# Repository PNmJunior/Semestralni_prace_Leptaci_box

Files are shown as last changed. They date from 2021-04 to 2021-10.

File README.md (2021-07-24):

# Semestrální práce Leptací box
Jedná se o semestrální prácí Pavla Ňachaje z předmětu PPC.
## Cíl
Sestrojit zařízení, které usnadní a zefektivní leptání oboustraných spojů.
## Výsledek
Podařilo se mi vytvořit zařízení a k tomu řídicí aplikaci, které splnily mojí počátečnou představu.
## Prostředky
* Aplikace v QT5, programováné ve VizualStudiu.
* Arduino Nano jako řídicí prvek celého Leptacího boxu.
* Navrhnutí specifických komponentů v OpenSCAD.
* Vytisknutí navržených komponent na 3D tiskárně.
## Poděkování
Chtěl bych poděkovat doc. Ing. Stanislavu Vítkovi Ph.D. za umožněni tisknout na 3D tiskárně ČVUT potřebné komponenty v době distanční výuky.
## Rozdělení souborů:
* "Dokumentace" - je soubor, kde jsou všechny dokumentační záležitosti.
* "OpenSCAD" - Je soubor, kde jsou navrhnuty všechny 3D objekty.
* "programovani" - Je soubor, kde jsou jak projekt aplikace, tak program k Arduinu, které řídí Leptací box.
* "Leptaci_box.pdf" - Dokumentace k semestrální práci.

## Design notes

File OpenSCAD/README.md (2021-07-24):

# OpenSCAD
V této složce jsou umístěné vymodelované 3D objekty pro Leptací box.
* soubor "Tisk_3D_Objektu.scad" je naprogramovaný v OpenSCAD. Jsou zde všechny komponenty a rozvržební pro 3D tiskárny. https://openscad.org/ 
* složka "3D_Tisk" je rozložení komponentů v .stl určená pro 3D tiskárnu. 
* složka "Komponenty" jsou exportované všechny navržené části do .stl .

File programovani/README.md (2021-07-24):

# programovani
* "AppDriverBete" - Je to alikace naspaná v QT5. 
* "DriverArduino" - Nakonec jsem pro progamování zvolil Arduino Nano, kvůli tomů, že mám s ním skušenosti.

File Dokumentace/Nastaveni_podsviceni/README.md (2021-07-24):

#Nastaveni podsvícení
PWM piny Arduina jsou schpny generovat pwm pulz v rozsahu od 0[0%] do 255[100%] intenzity svícení.
Ovšem realná intenzita svícení není lineárně úměrná vůči pwm pulzům.
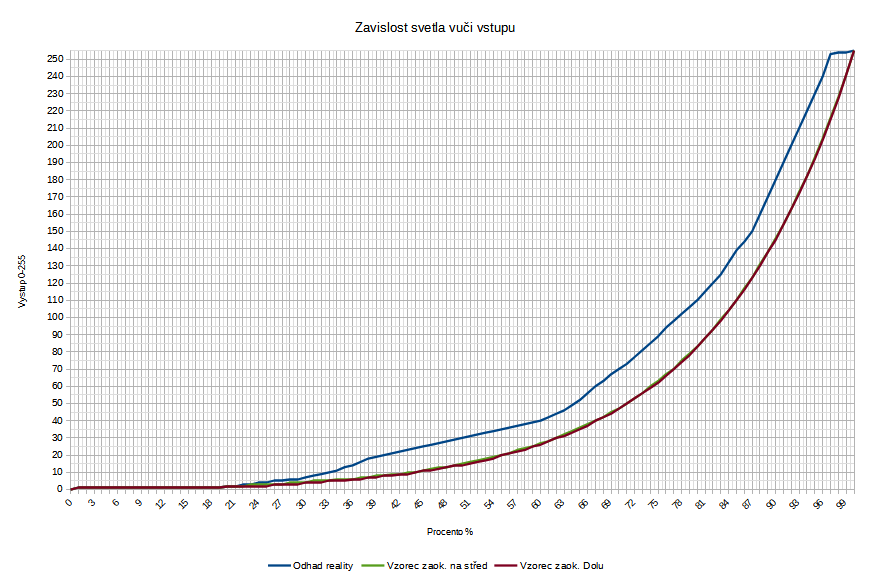
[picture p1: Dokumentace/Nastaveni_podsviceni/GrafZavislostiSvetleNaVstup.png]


## Tabulka převodu z procent na PWM

x = vstup v rozsahu od 0 do 100 v jednotce %

y = pwm výstup v rozsahu od 0 do 255

| rozsah x | vzorec | rozsah y| popis|
|---|---|---|---|
|0|y = 0|0|vypnuté světlo|
|1,19|y = 1|1|minimální světlo|
|20,99||2,241|regulace svícení|
|100|y = 255|255|maximalni svicení|

---

## Tabulka převodu z PWM na procenta

x = pwm výstup

y = procenta

| rozsah x | vzorec | rozsah y| popis|
|---|---|---|---|
|0|y = 0|0|vypnuté světlo|
|1|y = 10|10|minimální svícení odhadnuté na 10%|
|2,254||20,99|regulace svicení|
|255|y = 100|100|maximálni svicení|

Porovnání obou funkcí:

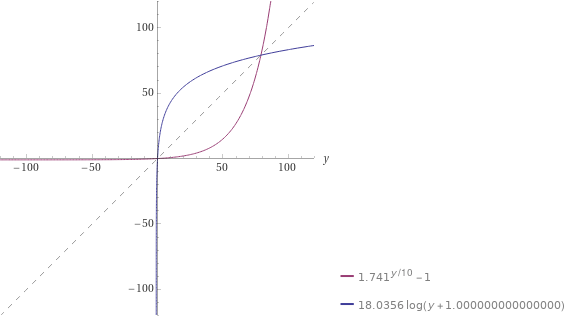
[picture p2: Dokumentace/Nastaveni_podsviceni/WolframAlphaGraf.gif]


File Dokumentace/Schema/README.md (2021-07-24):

# Schema

V pdf je schématicky znázorněné zapojeni.

* Schema zapojeni - Celkové propojeni

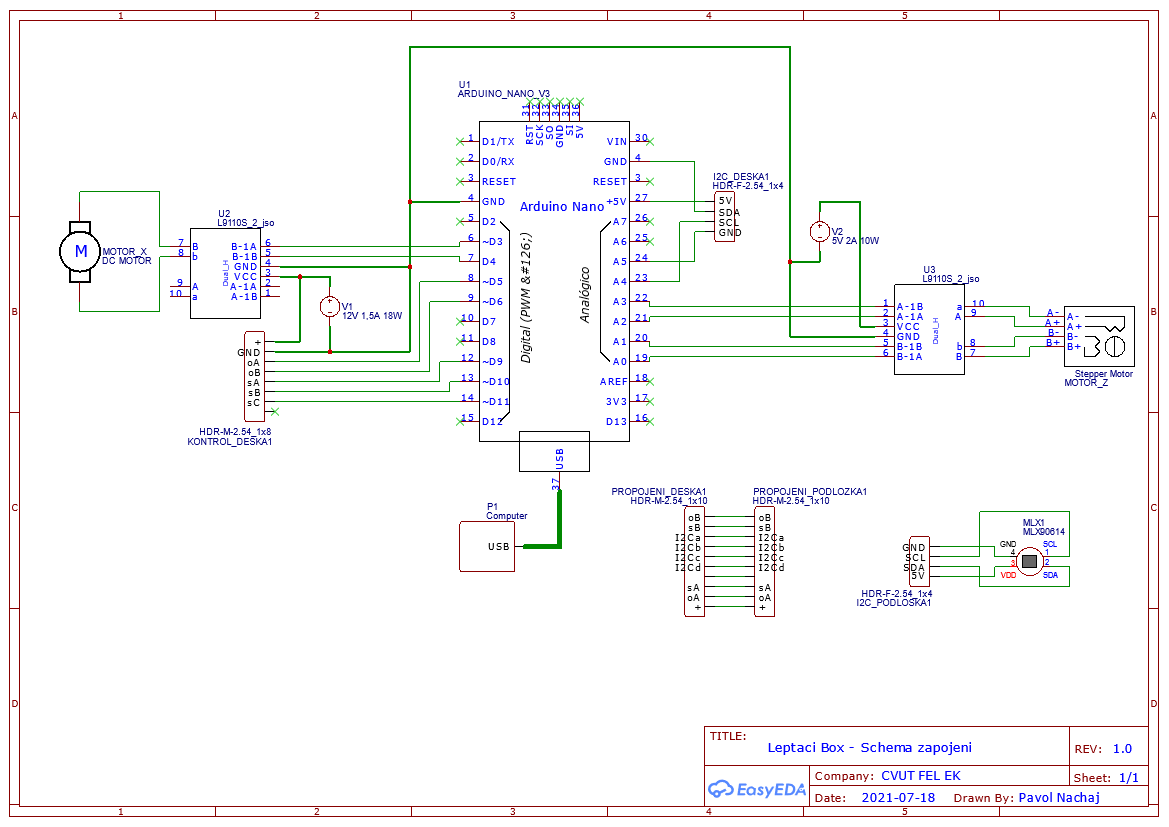
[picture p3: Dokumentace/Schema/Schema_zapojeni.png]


* Deska - Jde o plošný spoj vlastní výroby. Ovládá Desku.

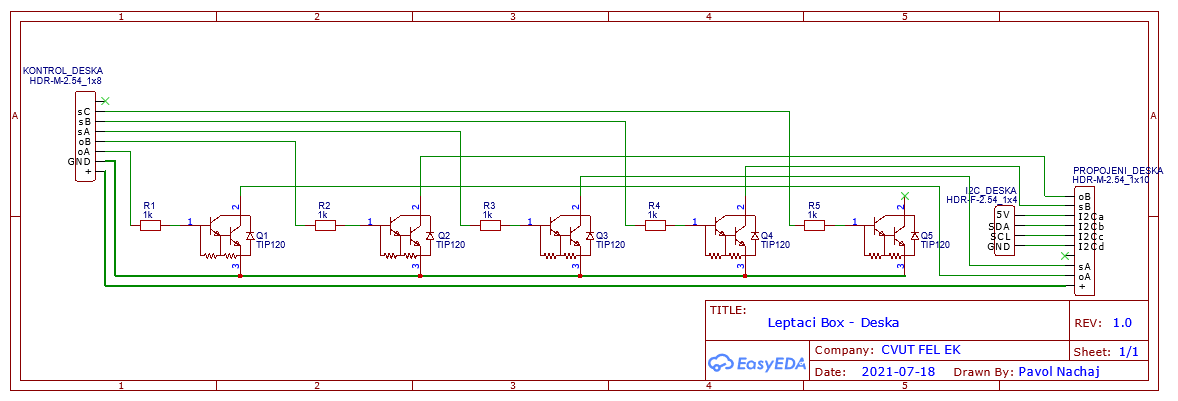
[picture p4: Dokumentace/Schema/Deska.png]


* Podlozka - Jde o konstrukci vlastní výroby, kde je umistěné podsvíceni misek a konektory pro topné tělesa... 

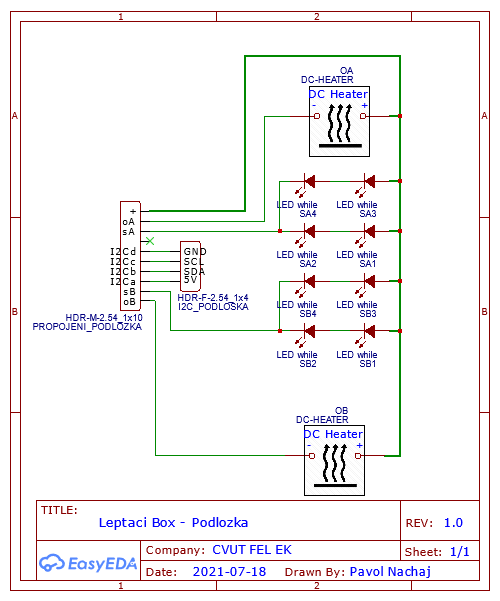
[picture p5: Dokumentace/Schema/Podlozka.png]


## Popis zapojeni soustavy

### Komponenty:

* Arduino Nano - Řidi celou elektroniku. Má funkci mikrokontrolóru.
* USB kabel, ktery spojuje Arduino s PC
* Zdroj napěti 5V
* Zdroj napěti 12V 2A
* H-můstek pro 12V, který ovládá MotorX
* H-můstek pro 5V, který ovládá MotorZ
* MotorX dc 12V motor, s proudovou špičkou kolem 1,5A
* MotorZ je "CD-ROM Stepper motor"
* Senzor teploty MLX90614. Jde o infračervený snimač. Měří jak teplotu okoli, tak i objektu, na který je namířený.
* Deska vlástni výroby. Spíná kontakty na podložce pro podsviceni a topeni.
* Podložka. Vlastni výroby.

###GND spojeno s:
* GND Arduino a následně:
    * USB kabel a zdroj počítače...
    * GND Senzor teploměru
* Zabudovaný zdroj 12V
* Zabudovaný zdroj 5V
* GND H-můstek pro 12V MotorX
* GND H-můstek pro 5V MotorZ
* GND deska vlastní výroby.

### Napájení:
#### 12V:
* Vcc H-můstek pro 12V MotorX
* (+) Deska vlastní výroby
#### 5V:
* Vcc H-můstek pro 5V MotorZ
#### USB 5V:
* Arduino 5V
* Vcc teploměr

## Zapojení Arduino Nano
Vyrobil jsem pomoci BSL vlasní konektory. Pojmenoval jsem je "Sloty". 
* Slot1 - 4 pin. od GND do D4
    * GND - země zdrojů
    * D3 pwm - Pwm kontroler motoru X
    * D4 - Kontroler motoru X
* Slot2 - 8 pinu od D5 do D12
    * D5 pwm - Ohřev A
    * D6 pwm - Ohřev B
    * D9 pwm - Světlo A
    * D10 pwm - Světlo B
    * D11 pwn - Světlo C
* Slot3 - 4 pinu do A0 do A3
    * A3 - konektor A- pro motor Z
    * A2 - konektor A+ pro motor Z
    * A1 - konektor B- pro motor Z
    * A0 - konektor A+ pro motor Z
* Slot4 - 8 pinu od A4 od VIN
    * GND - zep pro senzor MLX.
    * 5V - napájeni pro senzor MLX.
    * A5 - SCL pro senzor MLX.
    * A4 - SDA pro senzor MLX.

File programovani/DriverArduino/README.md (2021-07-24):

# DriverArduino

Program napsán pro Arduino Nano.

## Projekt obsahuje:

* "DriverArduino.ino" - Program pro Arduino Nano.
* "definice.h" - Soubor s definicemi stejný jak pro Arduino, tak pro Aplikaci. Nutné kvůli kompaktibilitě komunikačního protokolu.

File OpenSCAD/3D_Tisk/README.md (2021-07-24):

# 3D Tisk
Komponenty jsou zde uspořádané na ploše připravené k tisku na 3D tiskárně.
* NutneMinimum.stl - tisková plocha 100x120mm. Soustava komponentů, potřebná k nejnutnéjší funkci Leptacího boxu.
* VsechnyKomponenty.stl - tisková plocha 150x130mm. Soustava komponentů pro různé variace soustavy pro držení plošného spoje v Leptacím boxu.

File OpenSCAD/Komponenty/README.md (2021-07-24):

# Kompoenty
* HranUchytSt.stl - Obdelníkový nástavec určen pro přichycení plošného spoje.
    * Použíté v prezentačním videu.
* KulUchytSt.stl - Válcovitý nástavec určen pro přichycení plošného spoje.
* Nosnik_3mm.stl - Převodník mezi pohyblivou částí CD rom a zavitovými tyčemi, na kterých se nastavuje šířka plošného spoje. Výška převodníkové plochy je 3mm.
* Nosnik_4mm.stl - Převodník mezi pohyblivou částí CD rom a zavitovými tyčemi, na kterých se nastavuje šířka plošného spoje. Výška převodníkové plochy je 4mm.
    * Použíté v prezentačním videu.
* SenHoriz.stl - Pouzdro pro Infračervený senzor. Upevnění pomoci šroubové tyče nad misku.
* SenSroub.stl - Pouzdro pro Infračervený senzor. Upevnění a složení pouzdra pomoci šroubku a matiček. Uchycení přes Merkur ze strany misky.
    * Použíté v prezentačním videu.
* Spojka.stl - Převod mezi osou x na osu y.
    * Použíté v prezentačním videu.

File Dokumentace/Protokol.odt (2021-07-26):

ČESKÉ VYSOKÉ UČENÍ TECHNICKÉ V PRAZE
FAKULTA ELEKTROTECHNICKÁ

Semestrální práce
Z předmětu Praktické programování v C/C++ (B2B99PPC)

Pavol Ňachaj
Skupina 104

Leptací box

2021

# Úvod

Rozhodl jsem se, že si postavím Leptací box. Leptací box bude leptat plošné spoje a budu ho moct dálkově řídit. Uvnitř bude miska s leptací kapalinou Chlorid železitý ( FeCl3 )[1] a s vodou pro odstranění leptací kapaliny. Využil jsem k tomu semestrální práci z předmětu B2B99PPC v druhém semestru.

## Cíle

### Cíle Leptacího boxu

- Uvnitř boxu bude mechanizmus, který bude schopen přesunout oboustranný leptaný plošný spoj mezi miskami.
  - oboustranný plošný spoj znamená, že měděná vrstva je na obou stranách plastové desky.
- Zajištění ohřevu kapalin. Ideální teplota je kolem 40°C.[3]
- Zajištění promíchávání leptací směsi pro zefektivnění leptání. Pro odplavení nyní už FeCl2 , který zreagoval s mědí a tím zvýšil koncentraci FeCl3 na povrchu leptané plochy.[3]
- Podsvícení misek a možnost je přesvítit, pro odhad stavu vyleptaného plošného spoje.
- Měření teploty kapaliny s leptadlem.

### Cíle Aplikace

- Informovat o:
  - teplotě misky
  - detekci připojeného zařízeni jako Leptací box
- Regulovat:
  - Pohyb ramene s plošným spojem ve dvou osách (x, z), umožňující ponoření plošného spoje do kapaliny a pohyb plošného spoje mezi miskami.
  - Zapnout/vypnout promíchávání kapaliny pomoci vibrací.
  - Regulace podsvícení
  - Regulace teploty misky s možností vypnutí ohřevu po dosažení maximální teploty.
  - Predikovat vývoj teploty v grafu.

# Leptací box

## Úvod

Jako základ jsem použil nefunkční tiskárnu EPSON SX425W [2], kterou jsem rozebral a upravil pro potřeby projektu. Tím myslím vyrobení velkého prostoru uvnitř. Z původní tiskárny jsem ponechal box a lištu s motorem, po které se pohyboval jezdec s tiskovými hlavami.

Po odstranění všech úchytů a vrstev ode dna až po skenovací sklo, se objevil dostatečný prostor pro podložku, misky s kapalinou a mechanizmus manipulujicí s plošným spojem.

## Podložka

Podložka obsahuje LED moduly [4] pro podsvícení misek, konektory k topným tělesům a I2C konektor pro infračervený senzor teploty [5]. Pro uspořádání konstrukce jsem použil Univerzální plošné spoje [6] a komponenty stavebnice Totem Maker [12]. Jejich schéma je v příloze.

## Misky

Pro kapaliny používám misky z „hotových jídel“ z řetězce Lidl (Řadu produktů jako například [10]). Jejich výhodou je průhlednost a nízká cena. Dlouhodobými experimenty jsem se přesvědčil, že materiál misek je odolný vůči leptacímu roztoku.

## Přichycovací mechanizmus

Přichycovací mechanizmus je vyroben pomoci 3D tisku, kde jsem komponenty navrhl pomoci programu OpenSCAD [11]. Navrhl jsem několik variaci uchycení.

Návrhy jsou v: „seminarni_prace_leptaci_box\OpenSCAD“.

## Pohyb po ose Z (vertikálně)

Pro vertikální pohyb přichycovacího mechanizmu jsem použil část CD rom s krokovým motorem. Systém držení plošného spoje je připevněn na mechanizmus jezdce, kde byla čtečka dat z CD.

Krokový motor je ovládán přes Arduino pomoci H-můstku. Celá konstrukce pohyblivých částí osy Z je z CD rom.

## Pohyb po ose X (horizontálně)

Zde jsem použil původní mechanizmus z původní tiskárny. S lištou a její polohou, motorem pohybujícím jezdcem, mechanizmem pro pohyb jezdce a motor jsem nechal původní. Jezdec jsem pomoci Totemu [12] upravil tak, abych byl schopen spojit s konstrukcí CD rom.

## Lišta s elektronikou

Na lištu z původní tiskárny jsem zezadu připevnil plastovou lištu z Totemu [12], kde jsem umístil veškerou elektroniku.

Schémi můžete najít v příloze nebo v „seminarni_prace_leptaci_box\Dokumentace\Schema“.

## Mikrokontroler

Jako Mikrokontrolér řídicí celý Leptací box jsem si zvolil Arduino Nano[13], díky dobré zkušenosti s tímto mikrokontrolérem. Program můžete najít v „seminarni_prace_leptaci_box\programovani\DriverArduino“.

## H-Můstek

H-můstek je komponent, který umožňuje řídit Motory [7].

## Deska

Při výrobě této desky jsem vycházel z projektu [14]. Schéma, které odpovídá zapojení desky v Leptacím boxu, je v příloze.

Deska zajišťuje regulaci podsvícení a ohřev kapalin v miskách. Lze v budoucnu přidat i osvětlení celého boxu.

## Zdroje napětí

Zdroje napětí jsem umístil do krabičky, ve které byl původní zdroj, který ovšem byl naprosto nevyhovující pro aplikování v projektu, proto jsem to nahradil dvěma zdroji.

- 5V 2A 10W [8]
- 12V 1,5A 18W [9]

## Teploměr

Jako teploměr kapaliny jsem použil Infračervený teploměr MLX90614ESF-BAA [5], kvůli extrémnímu prostředí, ve kterém se nachází a kvůli leptacímu roztoku nejde měřit teplota kapaliny přímo dotykově.

## Topné těleso

Nenašel jsem žádné vhodné topné těleso, které by bylo vhodné do leptací kapaliny. Proto jsem použil drátový rezistor[15], který jsem obalil do elektrikářské samosmršťovací bužírky[16]. Bohužel tento odolný materiál není dokonalý tepelný vodič, a proto tepelný účinek na ohřev kapaliny není dostatečně rychlý, jak by bylo ideální. Žádnou vhodnější alternativu jsem nenašel.

# Software

Pokud není uvedeno jinak, čerpáno z QT5[19].

## Programovací prostředí

Programoval jsem to v QT[18] pomoci Visual Studio Code[17]

## QT5

Pro programování jsem použil QT5[19], protože obsahuje podporu pro knihovnu QSerialPort[20]. V průběhu vývoje byla vydaná QT 6.2 s podporou QSerialPort[22], ale já jsem už zůstal u QT5.

## QSerialPort

QSerialPort [20] používám k navázání seriálové komunikace. Pomoci této knihovny získávám seznam portu. Inicializuji komunikaci s Arduinem[21] v „main.c“ a komunikuji ve své knihovně „protokolKomunikace.h“.

## QComboBox

ComboBox používám k výběru daného portu.

## QPushButton a QSlider

Pomoci signálu „QPushButton::clicked“ a „QSlider::valueChanged“ mám obsažené všechny funkcionality programu, co se týká řízení Leptacího boxu a nastavení aplikace.

## QTimer

Pomoci signálu „ QTimer::timeout“ se aktualizuji data o teplotách a o ohřevu. Následně se provedou úkony k jejich vizualizaci na indikátorech, grafu a proměnných textech.

## QDoubleSpinBox

Používá se pro nastavení teploty, při které je automaticky ohřev vypnut.

## qcustomplot

Použito z materiálů z výuky [23]. Vykresluje graf s historii teploty kapaliny misky A i s její predikací.

## Grafické knihovny

- QHBoxLayout
- QVBoxLayout
- QLabel
- QFont
- QGridLayout – Pro rozmístění QPushButton v joysticku.
- QFrame – Oddělovací čáry mezi části programu.

## Ostatní použité knihovny

- QApplication
- QDebug
- QString
- QByteArray – Nutné pro práci s QSerialPort.
- QObject
- QThread – Uspání vlákna před zahájením komunikace, aby se Arduino mělo čas připravit.
- qmath.h

# Praktická ukázka

## Video

Odkaz na video: https://youtu.be/_YVxW2yeHDs [24].

## Aktualizace aplikace k 23.7.2021

Obraz programu z 23.07.2021 je v příloze „Obraz Aplikace z 23.07.2021.

# Důvody použitých komponentů

## Finanční stránka

Při realizaci projektu jsem se rozhodl použít již nefunkční tiskárnu a CD rom, abych výrazně snížil cenu projektu.

Co se týče mechanických komponentů, použil jsem to, co jsem měl k dispozici.

Alternativa k původnímu jezdci s lištou a motorem je například [25] s [26] za přibližně 1300Kč.

Alternativu k CD rom jsem našel motor se závitem [28] bez další konstrukce za 178Kč nebo vhodný mechanizmus [29] za 2500Kč.

Co se týče konstrukce, tak bych cenu dílů Totem[19] odhadl na 100Kč. Alternativu k možnostem tiskárny jsem nenašel. Každopádně by se cena pohybovala dohromady v tisících korunách.

Co se týče elektroniky [4],[5],[6],[7],[8],[9],[15],[16], klon [13] a další, tak ta stála přibližně 900kč. Všechnu elektroniku jsem nakoupil.

Co se týče komponentů vytisknutých na 3D tiskárně, tak jsem nenašel vhodnou alternativu ke komponentům, které jsem si nechal vytisknout.

## Výhody

Použitím bezcenné tiskárny jsem získal mechanizmus pohybu po ose x, box s možností přístupu ze předu, ze hora a bezproblémovým uzavřením boxu s průhledný stropem.

Použitím CD rom jsem získal pohybující mechanizmus na ose z.

## Vývoj

Co se týče ohřevu kapaliny, tak zde je prostor pro vývoj. Alternativu k mému řešení s drátovým rezistorem[15] a bužírce [16] jsem nenašel, kvůli absenci topných těles s jiným povrchem než kov.

V budoucnu možný přechod řízení místo USB přes Wifi / Bluetooth.

# Závěr

Podařilo se mi úspěšně využít do projektu nefunkční tiskárnu a CD rom. Tím jsem ušetřil jak peníze, tak životní prostředí tím, že nebude nutné recyklovat materiály, které jsem díky tomu nenakoupil, nepřepravil… U boxu z tiskárny jsem navíc získal funkcionality, které by se mi obtížně vyráběly.

Aplikace je formátována na výšku, kvůli možnosti v budoucnu přejít na bezdrátovou komunikaci a tím umožnit pohodlný přestup na mobilní aplikaci.

Myslím si, že se mi projekt vydařil.

# Literatura

1. MACHINING, Chemical. Chemické obrábění: Používaná rozpouštědla [online]. Ústav technologie obrábění, projektování a metrologie, 2018 [cit. 2021-7-19]. Dostupné z: https://dspace.cvut.cz/bitstream/handle/10467/79561/F2-BP-2018-Faltejsek-Jakub-BP_s_formatovanim.pdf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. Bakalařská práce. Fakulta Strojni CVUT. Vedoucí práce Ing. Pavel NOVÁK, Ph.D.
2. Epson Stylus SX425W. EPSON [online]. [cit. 2021-7-23]. Dostupné z: https://www.epson.cz/products/printers/inkjet-printers/for-home/epson-stylus-sx425w
3. Chlorid zelezity. MCUforum [online]. [cit. 2021-7-19]. Dostupné z: http://mcu.cz/forum_m/showthread.php?tid=56&
4. LED modul 1,2W/12V 100lm studená bílá, 2x SMD2835 IP65 SEM-S27CW. GME [online]. [cit. 2021-7-19]. Dostupné z: https://www.gme.cz/led-modul-vodotesny-2x-led-studena-bila-54x18mm-ip65
5. Infračervený teploměr MLX90614ESF-BAA. Laskarduino [online]. [cit. 2021-7-19]. Dostupné z: https://www.laskarduino.cz/infracerveny-teplomer-mlx90614esf-baa/
6. 50x70mm PCB prototypová deska. Laskarduino [online]. [cit. 2021-7-19]. Dostupné z: https://www.laskarduino.cz/50x70mm-pcb-prototypova-deska/
7. H-můstek L9110S, dvoumotorový modul. Laskarduino [online]. [cit. 2021-7-19]. Dostupné z: https://www.laskarduino.cz/h-mustek-radic-l9110s/
8. DK112 napájecí 230V AC-DC zdroj 5V/2A, izolovaný. Laskarduino [online]. [cit. 2021-7-19]. Dostupné z: https://www.laskarduino.cz/ac-dc-izolovany-zdroj-dk112-5v-2a/
9. DK112 napájecí 230V AC-DC zdroj 12V/1.5A, izolovaný. Laskarduino [online]. [cit. 2021-7-19]. Dostupné z: https://www.laskarduino.cz/ac-dc-izolovany-zdroj-dk112-12v-1-5a/
10. Lidl rozšiřuje sortiment hotových jídel. MediaGuru.cz [online]. [cit. 2021-7-19]. Dostupné z: https://www.mediaguru.cz/clanky/2020/05/lidl-rozsiruje-sortiment-hotovych-jidel/
11. OpenSCAD [online]. [cit. 2021-7-19]. Dostupné z: https://openscad.org/
12. Totem [online]. [cit. 2021-7-19]. Dostupné z: https://totemmaker.net/
13. Arduino Nano. : ARDUINO STORE [online]. [cit. 2021-7-19]. Dostupné z: https://store.arduino.cc/arduino-nano
14. Transistors With Arduino (BJT) - BC547 TIP120. Instructables [online]. [cit. 2021-7-19]. Dostupné z: https://www.instructables.com/Transistors-With-Arduino-BJT-BC547-TIP120/
15. Drátový rezistor THT v keramice RD 27R 10W 5%. GME [online]. [cit. 2021-7-19]. Dostupné z: https://www.gme.cz/rd-27r-10w-5
16. Smršťovací bužírka 6.4mm, 2:1, černá K32-6 black. GME [online]. [cit. 2021-7-19]. Dostupné z: https://www.gme.cz/smrstovaci-buzirka-kss-f0927f-6
17. Visual Studio Code [online]. [cit. 2021-7-23]. Dostupné z: https://code.visualstudio.com/
18. QT [online]. [cit. 2021-7-23]. Dostupné z: https://www.qt.io/
19. Qt 5.15. QT [online]. [cit. 2021-7-23]. Dostupné z: https://doc.qt.io/qt-5/
20. Qt Serial Port. QT [online]. [cit. 2021-7-23]. Dostupné z: https://doc.qt.io/qt-5/qtserialport-index.html
21. Sending a data to Arduino through serial port using Qt. QT Forum [online]. [cit. 2021-7-23]. Dostupné z: https://forum.qt.io/topic/64696/sending-a-data-to-arduino-through-serial-port-using-qt
22. Qt Serial Port. QT [online]. [cit. 2021-7-23]. Dostupné z: https://doc-snapshots.qt.io/qt6-dev/qtserialport-index.html
23. Ppc/tutorials/tut12/02-covid. GitLab [online]. [cit. 2021-7-23]. Dostupné z: git@gitlab.fel.cvut.cz:viteks/ppc.git ; https://gitlab.fel.cvut.cz/viteks/ppc/-/tree/master/tutorials/tut12/02-covid
24. Prakticka ukazka Leptaci Box. YouTube [online]. 2021 [cit. 2021-7-24]. Dostupné z: https: //youtu.be/_YVxW2yeHDs
25. Sada Machifit pro lineární pohyb 400 mm. GME [online]. [cit. 2021-7-24]. Dostupné z: https://www.gme.cz/sada-machifit-pro-linearni-pohyb-400-mm
26. DC motor krokový 5V/2A pro tiskárny Nema 17. GME [online]. [cit. 2021-7-24]. Dostupné z: https://www.gme.cz/krokovy-motor-nema-17
27. Plastová deska "Guttagliss Hobbycolor", bílá, 50 cm x 150 cm. OBI [online]. [cit. 2021-7-24]. Dostupné z: https://www.obi.cz/plastove-stresni-krytiny/plastova-deska-guttagliss-hobbycolor-bila-50-cm-x-150-cm/p/2991693
28. GA12-N20 motor s převodovkou 12V 500RPM se šnekem M4x55mm. Laskarduino [online]. [cit. 2021-7-24]. Dostupné z: https://www.laskarduino.cz/ga12-n20-motor-s-prevodovkou-12v-500rpm-se-snekem-m4x55mm/
29. Prizmatický lineární pojezd 100mm s kuličkovým šoubem a krokovým motorem. Postav Robota [online]. [cit. 2021-7-24]. Dostupné z: https://www.postavrobota.cz/Prizmaticky-linearni-pojezd-100mm-s-kulickovym-soubem-a-krokovym-motorem-d1948.htm

# Přílohy:

## Schéma zapojení Leptacího boxu

- Schema zapojeni – Ukazuje propojení všech komponentů.
- Deska – Je schéma desky, kterou jsme vyrobil.
- Podložka – Je zapojení podložky.

### Schema zapojeni


### Deska

### Podložka


## Obraz Aplikace z 23.07.2021

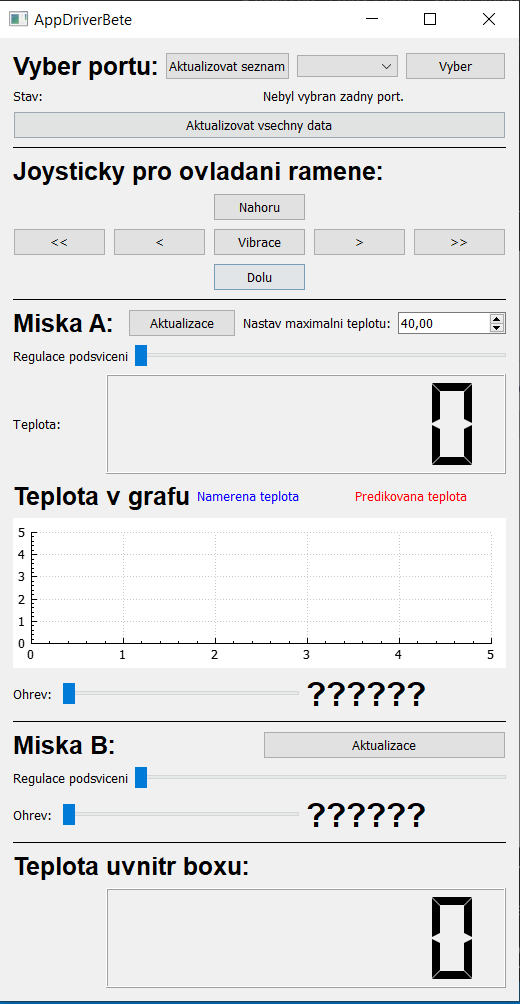
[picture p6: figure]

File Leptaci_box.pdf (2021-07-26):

## ČESKÉ VYSOKÉ UČENÍ TECHNICKÉ V PRAZE FAKULTA ELEKTROTECHNICKÁ

# Semestrální práce

## Z předmětu Praktické programování v C/C++ (B2B99PPC)

## Pavol Ňachaj Skupina 104

# Leptací box

2021

### Obsah

## 1 . Úvod

Rozhodl jsem se, že si postavím Leptací box. Leptací box bude leptat plošné spoje a budu ho moct dálkově řídit. Uvnitř bude miska s leptací kapalinou Chlorid železitý ( FeCl3 )[1] a s vodou pro odstranění leptací kapaliny. Využil jsem k tomu semestrální práci z předmětu B2B99PPC v druhém semestru.

### 1.1 . Cíle

1.1.1 . Cíle Leptacího boxu
- Uvnitř boxu bude mechanizmus, který bude schopen přesunout oboustranný leptaný plošný spoj mezi miskami.
- oboustranný plošný spoj znamená, že měděná vrstva je na obou stranách plastové desky.
- Zajištění ohřevu kapalin. Ideální teplota je kolem 40°C.[3]
- Zajištění promíchávání leptací směsi pro zefektivnění leptání. Pro odplavení nyní už FeCl2 , který zreagoval s mědí a tím zvýšil koncentraci FeCl3 na povrchu leptané plochy.[3]
- Podsvícení misek a možnost je přesvítit, pro odhad stavu vyleptaného plošného spoje.
- Měření teploty kapaliny s leptadlem.

1.1.2 . Cíle Aplikace
- Informovat o:
- teplotě misky
- detekci připojeného zařízeni jako Leptací box

- Regulovat:
- Pohyb ramene s plošným spojem ve dvou osách (x, z), umožňující ponoření plošného spoje do kapaliny a pohyb plošného spoje mezi miskami.
- Zapnout/vypnout promíchávání kapaliny pomoci vibrací.
- Regulace podsvícení
- Regulace teploty misky s možností vypnutí ohřevu po dosažení maximální teploty.
- Predikovat vývoj teploty v grafu.

## 2 . Leptací box

### 2.1 . Úvod

Jako základ jsem použil nefunkční tiskárnu EPSON SX425W [2], kterou jsem rozebral a upravil pro potřeby projektu. Tím myslím vyrobení velkého prostoru uvnitř. Z původní tiskárny jsem ponechal box a lištu s motorem, po které se pohyboval jezdec s tiskovými hlavami.

Po odstranění všech úchytů a vrstev ode dna až po skenovací sklo, se objevil dostatečný prostor pro podložku, misky s kapalinou a mechanizmus manipulujicí s plošným spojem.

### 2.2 . Podložka

Podložka obsahuje LED moduly [4] pro podsvícení misek, konektory k topným tělesům a I2C konektor pro infračervený senzor teploty [5]. Pro uspořádání konstrukce jsem použil Univerzální plošné spoje [6] a komponenty stavebnice Totem Maker [12]. Jejich schéma je v příloze.

### 2.3 . Misky

Pro kapaliny používám misky z „hotových jídel“ z řetězce Lidl (Řadu produktů jako například [10]). Jejich výhodou je průhlednost a nízká cena. Dlouhodobými experimenty jsem se přesvědčil, že materiál misek je odolný vůči leptacímu roztoku.

### 2.4 . Přichycovací mechanizmus

Přichycovací mechanizmus je vyroben pomoci 3D tisku, kde jsem komponenty navrhl pomoci programu OpenSCAD [11]. Navrhl jsem několik variaci uchycení.

Návrhy jsou v: „seminarni_prace_leptaci_box\OpenSCAD“.

### 2.5 . Pohyb po ose Z (vertikálně)

Pro vertikální pohyb přichycovacího mechanizmu jsem použil část CD rom s krokovým motorem. Systém držení plošného spoje je připevněn na mechanizmus jezdce, kde byla čtečka dat z CD.

Krokový motor je ovládán přes Arduino pomoci H-můstku. Celá konstrukce pohyblivých částí osy Z je z CD rom.

### 2.6 . Pohyb po ose X (horizontálně)

Zde jsem použil původní mechanizmus z původní tiskárny. S lištou a její polohou, motorem pohybujícím jezdcem, mechanizmem pro pohyb jezdce a motor jsem nechal původní. Jezdec jsem pomoci Totemu [12] upravil tak, abych byl schopen spojit s konstrukcí CD rom.

### 2.7 . Lišta s elektronikou

Na lištu z původní tiskárny jsem zezadu připevnil plastovou lištu z Totemu [12], kde jsem umístil veškerou elektroniku.

Schémi můžete najít v příloze nebo v „seminarni_prace_leptaci_box\ Dokumentace\Schema“.

### 2.8 . Mikrokontroler

Jako Mikrokontrolér řídicí celý Leptací box jsem si zvolil Arduino Nano[13], díky dobré zkušenosti s tímto mikrokontrolérem. Program můžete najít v „seminarni_prace_leptaci_box\programovani\DriverArduino“.

### 2.9 . H-Můstek

H-můstek je komponent, který umožňuje řídit Motory [7].

### 2.10 . Deska

Při výrobě této desky jsem vycházel z projektu [14]. Schéma, které odpovídá zapojení desky v Leptacím boxu, je v příloze.

Deska zajišťuje regulaci podsvícení a ohřev kapalin v miskách. Lze v budoucnu přidat i osvětlení celého boxu.

### 2.11 . Zdroje napětí

Zdroje napětí jsem umístil do krabičky, ve které byl původní zdroj, který ovšem byl naprosto nevyhovující pro aplikování v projektu, proto jsem to nahradil dvěma zdroji.

- 5V 2A 10W [8]
- 12V 1,5A 18W [9]

### 2.12 . Teploměr

Jako teploměr kapaliny jsem použil Infračervený teploměr MLX90614ESF-BAA [5], kvůli extrémnímu prostředí, ve kterém se nachází a kvůli leptacímu roztoku nejde měřit teplota kapaliny přímo dotykově.

### 2.13 . Topné těleso

Nenašel jsem žádné vhodné topné těleso, které by bylo vhodné do leptací kapaliny. Proto jsem použil drátový rezistor[15], který jsem obalil do elektrikářské samosmršťovací bužírky[16]. Bohužel tento odolný materiál není dokonalý tepelný vodič, a proto tepelný účinek na ohřev kapaliny není dostatečně rychlý, jak by bylo ideální. Žádnou vhodnější alternativu jsem nenašel.

## 3 . Software

Pokud není uvedeno jinak, čerpáno z QT5[19].

### 3.1 . Programovací prostředí

Programoval jsem to v QT[18] pomoci Visual Studio Code[17]

3.2 . QT5
Pro programování jsem použil QT5[19], protože obsahuje podporu pro knihovnu QSerialPort[20]. V průběhu vývoje byla vydaná QT 6.2 s podporou QSerialPort[22], ale já jsem už zůstal u QT5.

### 3.3 . QSerialPort

QSerialPort [20] používám k navázání seriálové komunikace. Pomoci této knihovny získávám seznam portu. Inicializuji komunikaci s Arduinem[21] v „main.c“ a komunikuji ve své knihovně „protokolKomunikace.h“.

### 3.4 . QComboBox

ComboBox používám k výběru daného portu.

### 3.5 . QPushButton a QSlider

Pomoci signálu „QPushButton::clicked“ a „QSlider::valueChanged“ mám obsažené všechny funkcionality programu, co se týká řízení Leptacího boxu a nastavení aplikace.

### 3.6 . QTimer

Pomoci signálu „ QTimer::timeout“ se aktualizuji data o teplotách a o ohřevu. Následně se provedou úkony k jejich vizualizaci na indikátorech, grafu a proměnných textech.

### 3.7 . QDoubleSpinBox

Používá se pro nastavení teploty, při které je automaticky ohřev vypnut.

### 3.8 . qcustomplot

Použito z materiálů z výuky [23]. Vykresluje graf s historii teploty kapaliny misky A i s její predikací.

### 3.9 . Grafické knihovny

- QHBoxLayout
- QVBoxLayout
- QLabel
- QFont
- QGridLayout – Pro rozmístění QPushButton v joysticku.
- QFrame – Oddělovací čáry mezi části programu.

### 3.10 . Ostatní použité knihovny

- QApplication
- QDebug
- QString
- QByteArray – Nutné pro práci s QSerialPort.
- QObject
- QThread – Uspání vlákna před zahájením komunikace, aby se Arduino mělo čas připravit.
- qmath.h

## 4 . Praktická ukázka

### 4.1 . Video

Odkaz na video: https://youtu.be/_YVxW2yeHDs [24].

### 4.2 . Aktualizace aplikace k 23.7.2021

Obraz programu z 23.07.2021 je v příloze „Obraz Aplikace z 23.07.2021.

## 5 . Důvody použitých komponentů

### 5.1 . Finanční stránka

Při realizaci projektu jsem se rozhodl použít již nefunkční tiskárnu a CD rom, abych výrazně snížil cenu projektu.

Co se týče mechanických komponentů, použil jsem to, co jsem měl k dispozici.

Alternativa k původnímu jezdci s lištou a motorem je například [25] s [26] za přibližně 1300Kč.

Alternativu k CD rom jsem našel motor se závitem [28] bez další konstrukce za 178Kč nebo vhodný mechanizmus [29] za 2500Kč.

Co se týče konstrukce, tak bych cenu dílů Totem[19] odhadl na 100Kč. Alternativu k možnostem tiskárny jsem nenašel. Každopádně by se cena pohybovala dohromady v tisících korunách.

Co se týče elektroniky [4],[5],[6],[7],[8],[9],[15],[16], klon [13] a další, tak ta stála přibližně 900kč. Všechnu elektroniku jsem nakoupil.

Co se týče komponentů vytisknutých na 3D tiskárně, tak jsem nenašel vhodnou alternativu ke komponentům, které jsem si nechal vytisknout.

### 5.2 . Výhody

Použitím bezcenné tiskárny jsem získal mechanizmus pohybu po ose x, box s možností přístupu ze předu, ze hora a bezproblémovým uzavřením boxu s průhledný stropem.

Použitím CD rom jsem získal pohybující mechanizmus na ose z.

### 5.3 . Vývoj

Co se týče ohřevu kapaliny, tak zde je prostor pro vývoj. Alternativu k mému řešení s drátovým rezistorem[15] a bužírce [16] jsem nenašel, kvůli absenci topných těles s jiným povrchem než kov.

V budoucnu možný přechod řízení místo USB přes Wifi / Bluetooth.

## 6 . Závěr

Podařilo se mi úspěšně využít do projektu nefunkční tiskárnu a CD rom. Tím jsem ušetřil jak peníze, tak životní prostředí tím, že nebude nutné recyklovat materiály, které jsem díky tomu nenakoupil, nepřepravil… U boxu z tiskárny jsem navíc získal funkcionality, které by se mi obtížně vyráběly.

Aplikace je formátována na výšku, kvůli možnosti v budoucnu přejít na bezdrátovou komunikaci a tím umožnit pohodlný přestup na mobilní aplikaci.

Myslím si, že se mi projekt vydařil.

## 7 . Literatura

[1] MACHINING, Chemical. Chemické obrábění: Používaná rozpouštědla [online]. Ústav technologie obrábění, projektování a metrologie, 2018 [cit. 2021-7-19]. Dostupné z:
https://dspace.cvut.cz/bitstream/handle/10467/79561/F2-BP-2018-Faltejsek-Jakub-BP_s_formatovanim.pdf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. Bakalařská práce. Fakulta Strojni CVUT. Vedoucí práce Ing. Pavel NOVÁK, Ph.D.
[2] Epson Stylus SX425W. EPSON [online]. [cit. 2021-7-23]. Dostupné z: https://www.epson.cz/products/printers/inkjet-printers/for-home/epson-stylussx425w
[3] Chlorid zelezity. MCUforum [online]. [cit. 2021-7-19]. Dostupné z: http://mcu.cz/forum_m/showthread.php?tid=56&
[4] LED modul 1,2W/12V 100lm studená bílá, 2x SMD2835 IP65 SEM-S27CW. GME [online]. [cit. 2021-7-19]. Dostupné z: https://www.gme.cz/led-modulvodotesny-2x-led-studena-bila-54x18mm-ip65
[5] Infračervený teploměr MLX90614ESF-BAA. Laskarduino [online]. [cit. 2021-7-19]. Dostupné z: https://www.laskarduino.cz/infracerveny-teplomermlx90614esf-baa/
[6] 50x70mm PCB prototypová deska. Laskarduino [online]. [cit. 2021-7-19]. Dostupné z: https://www.laskarduino.cz/50x70mm-pcb-prototypova-deska/
[7] H-můstek L9110S, dvoumotorový modul. Laskarduino [online]. [cit. 2021-7-19]. Dostupné z: https://www.laskarduino.cz/h-mustek-radic-l9110s/
[8] DK112 napájecí 230V AC-DC zdroj 5V/2A, izolovaný. Laskarduino [online]. [cit. 2021-7-19]. Dostupné z: https://www.laskarduino.cz/ac-dc-izolovanyzdroj-dk112-5v-2a/

[9] DK112 napájecí 230V AC-DC zdroj 12V/1.5A, izolovaný. Laskarduino [online]. [cit. 2021-7-19]. Dostupné z: https://www.laskarduino.cz/ac-dcizolovany-zdroj-dk112-12v-1-5a/
[10] Lidl rozšiřuje sortiment hotových jídel. MediaGuru.cz [online]. [cit. 2021-7-19]. Dostupné z: https://www.mediaguru.cz/clanky/2020/05/lidl-rozsirujesortiment-hotovych-jidel/
[11] OpenSCAD [online]. [cit. 2021-7-19]. Dostupné z: https://openscad.org/
[12] Totem [online]. [cit. 2021-7-19]. Dostupné z: https://totemmaker.net/
[13] Arduino Nano. : ARDUINO STORE [online]. [cit. 2021-7-19]. Dostupné z: https://store.arduino.cc/arduino-nano
[14] Transistors With Arduino (BJT) - BC547 TIP120. Instructables [online]. [cit. 2021-7-19]. Dostupné z: https://www.instructables.com/Transistors-With-Arduino-BJT-BC547-TIP120/
[15] Drátový rezistor THT v keramice RD 27R 10W 5%. GME [online]. [cit. 2021-7-19]. Dostupné z: https://www.gme.cz/rd-27r-10w-5
[16] Smršťovací bužírka 6.4mm, 2:1, černá K32-6 black. GME [online]. [cit. 2021-7-19]. Dostupné z: https://www.gme.cz/smrstovaci-buzirka-kss-f0927f-6
[17] Visual Studio Code [online]. [cit. 2021-7-23]. Dostupné z: https://code.visualstudio.com/
[18] QT [online]. [cit. 2021-7-23]. Dostupné z: https://www.qt.io/
[19] Qt 5.15. QT [online]. [cit. 2021-7-23]. Dostupné z: https://doc.qt.io/qt-5/
[20] Qt Serial Port. QT [online]. [cit. 2021-7-23]. Dostupné z: https://doc.qt.io/qt-5/qtserialport-index.html

[21] Sending a data to Arduino through serial port using Qt. QT Forum [online]. [cit. 2021-7-23]. Dostupné z: https://forum.qt.io/topic/64696/sending-a-datato-arduino-through-serial-port-using-qt
[22] Qt Serial Port. QT [online]. [cit. 2021-7-23]. Dostupné z: https://docsnapshots.qt.io/qt6-dev/qtserialport-index.html
[23] Ppc/tutorials/tut12/02-covid. GitLab [online]. [cit. 2021-7-23]. Dostupné z: git@gitlab.fel.cvut.cz:viteks/ppc.git ; https://gitlab.fel.cvut.cz/viteks/ppc/-/tree/master/tutorials/tut12/02-covid
[24] Prakticka ukazka Leptaci Box. YouTube [online]. 2021 [cit. 2021-7-24]. Dostupné z: https: //youtu.be/_YVxW2yeHDs
[25] Sada Machifit pro lineární pohyb 400 mm. GME [online]. [cit. 2021-7-24]. Dostupné z: https://www.gme.cz/sada-machifit-pro-linearni-pohyb-400-mm
[26] DC motor krokový 5V/2A pro tiskárny Nema 17. GME [online]. [cit. 2021-7-24]. Dostupné z: https://www.gme.cz/krokovy-motor-nema-17
[27] Plastová deska "Guttagliss Hobbycolor", bílá, 50 cm x 150 cm. OBI [online]. [cit. 2021-7-24]. Dostupné z: https://www.obi.cz/plastove-stresni-krytiny/plastova-deska-guttaglisshobbycolor-bila-50-cm-x-150-cm/p/2991693
[28] GA12-N20 motor s převodovkou 12V 500RPM se šnekem M4x55mm. Laskarduino [online]. [cit. 2021-7-24]. Dostupné z: https://www.laskarduino.cz/ga12-n20-motor-s-prevodovkou-12v-500rpm-sesnekem-m4x55mm/
[29] Prizmatický lineární pojezd 100mm s kuličkovým šoubem a krokovým motorem. Postav Robota [online]. [cit. 2021-7-24]. Dostupné z: https://www.postavrobota.cz/Prizmaticky-linearni-pojezd-100mm-skulickovym-soubem-a-krokovym-motorem-d1948.htm

## 8 . Přílohy:

### Seznam příloh

### 8.1 . Schéma zapojení Leptacího boxu

- Schema zapojeni – Ukazuje propojení všech komponentů.
- Deska – Je schéma desky, kterou jsme vyrobil.
- Podložka – Je zapojení podložky.


8.1.1 . Schema zapojeni

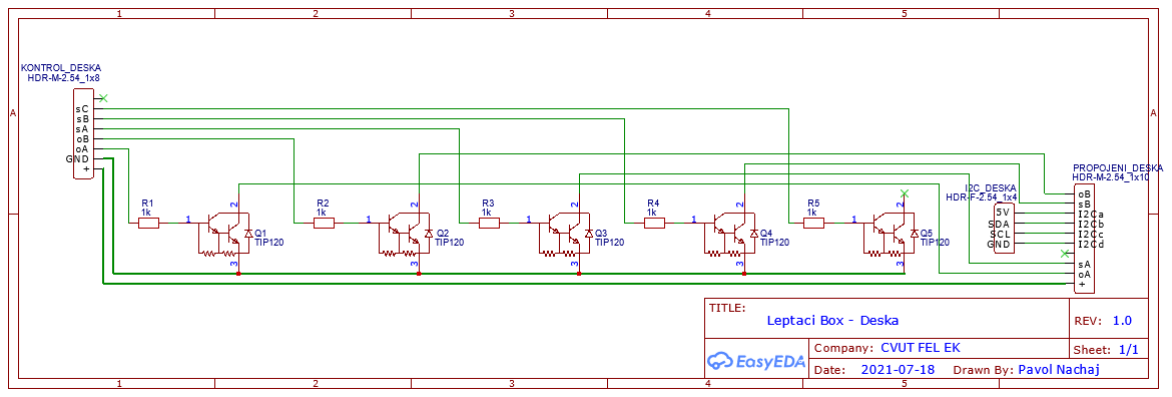
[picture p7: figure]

8.1.2 . Deska

8.1.3 . Podložka

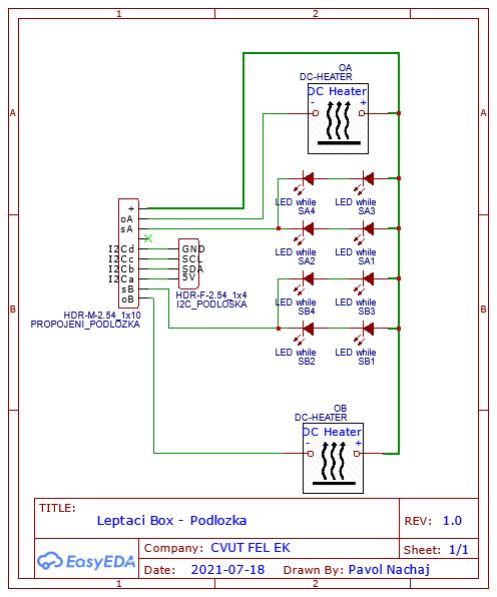
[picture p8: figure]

8.2 . Obraz Aplikace z 23.07.2021

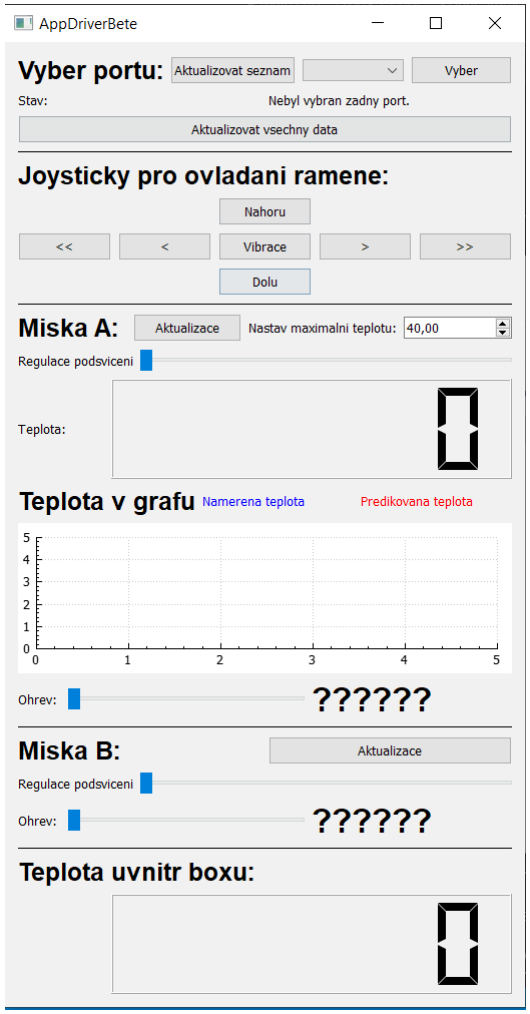
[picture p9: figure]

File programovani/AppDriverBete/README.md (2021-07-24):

# AppDriverBete

Aplikace je naprogramovaná v QT5 kvůli podpoře QSerialPort.h

## Projekt obsahuje:

* "AppDriverBete.pro" - Vytváření aplikace v release.
* "main.cpp" - Naprogramovaná aplikace.
* "definice.h" - Soubor s definicemi stejný jak pro Arduino, tak pro Aplikaci. Nutné kvůli kompaktibilitě komunikačního protokolu.
* "protokolKomunikace.h" - Obstarává komunikaci s Arduinem pro Aplikaci.
* "qcustomplot.h" a "qcustomplot.cpp" - Vytvoření grafu. Zdroj Studijní materiály.

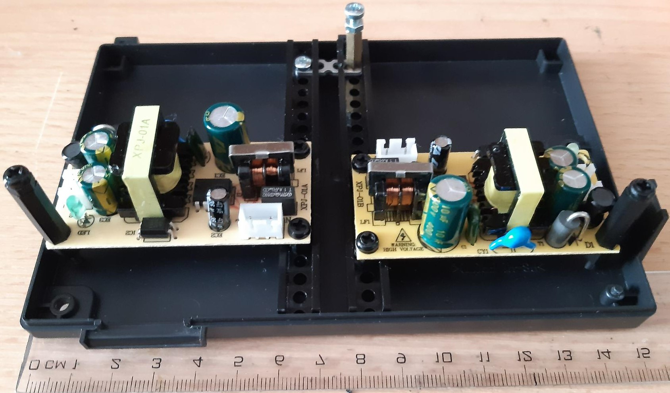
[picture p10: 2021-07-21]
Dokumentace/Napajeci_zdroje/Otevreny_Napajeci_Krabicka.png

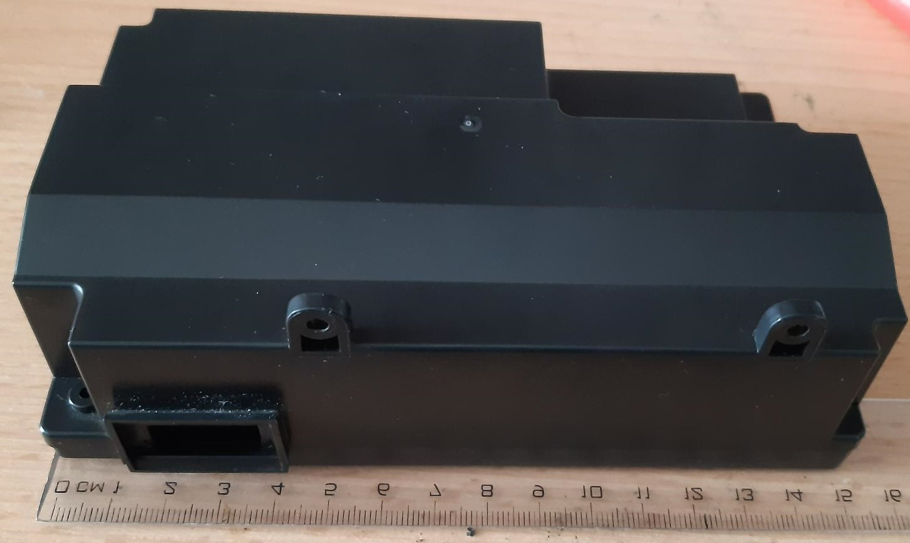
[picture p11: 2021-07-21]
Dokumentace/Napajeci_zdroje/Uzavrena_Napajeci_Krabicka.png

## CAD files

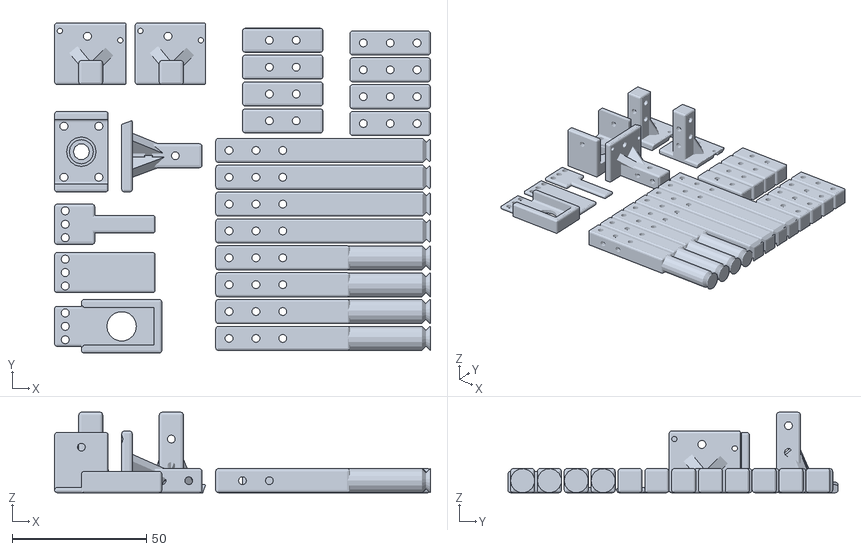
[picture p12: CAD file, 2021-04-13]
OpenSCAD/3D_Tisk/VsechnyKomponenty.stl
140.0 x 123.0 x 30.0

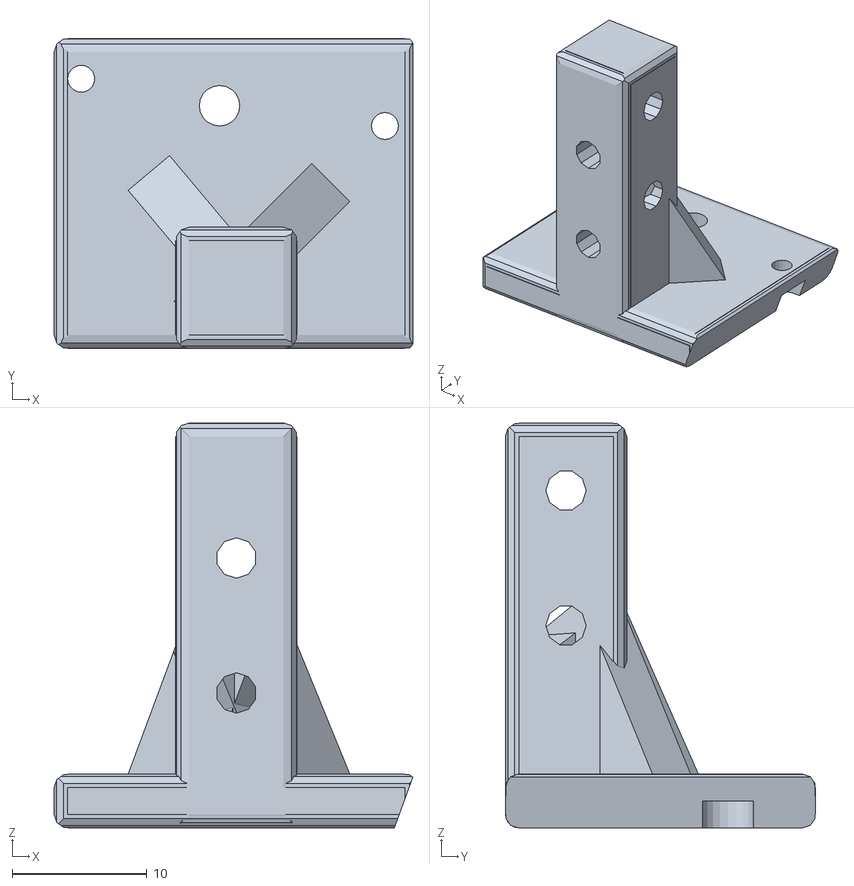
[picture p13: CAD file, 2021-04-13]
OpenSCAD/Komponenty/Nosnik_4mm.stl
26.6 x 23.0 x 30.0

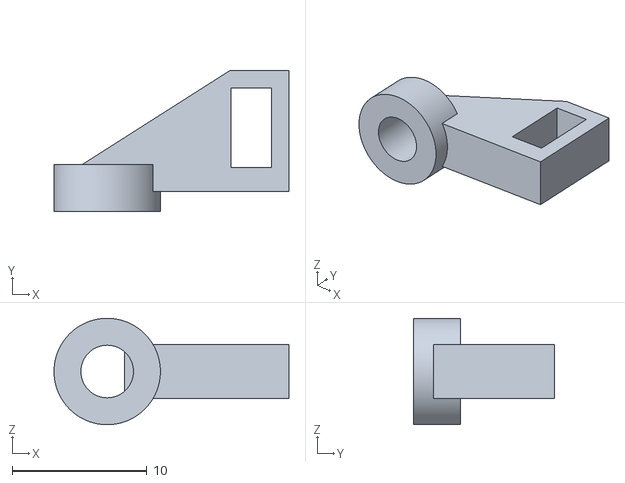
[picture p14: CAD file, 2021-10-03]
OpenSCAD/Strikackove_mechanizmus/Variable_Resistance_Connection_Block_LaLaRC.stl
17.4 x 10.5 x 7.90

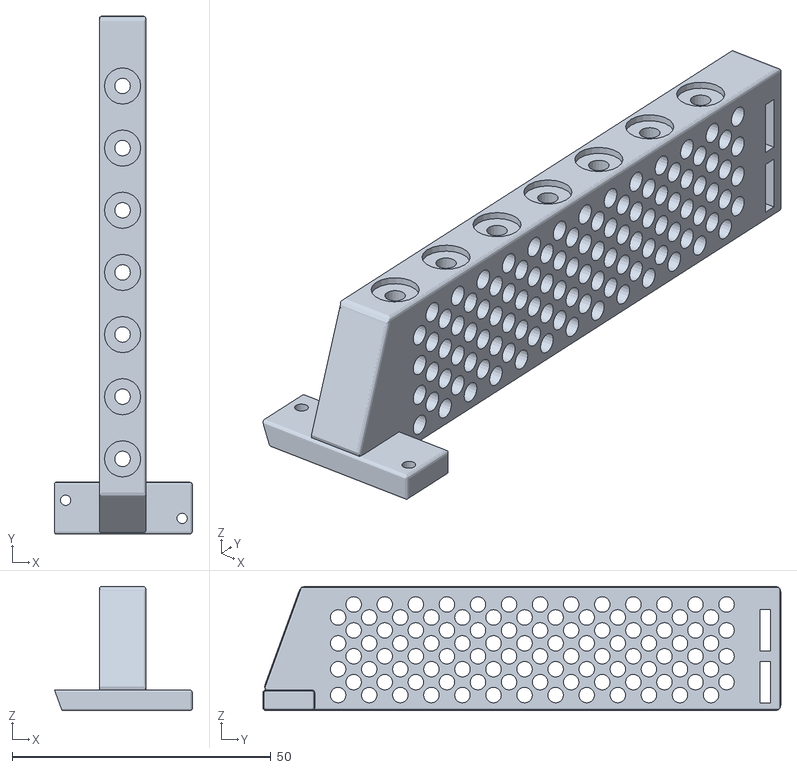
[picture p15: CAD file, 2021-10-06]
OpenSCAD/Tisk_3D_ObjektuV2aa.stl
26.6 x 100.0 x 24.0

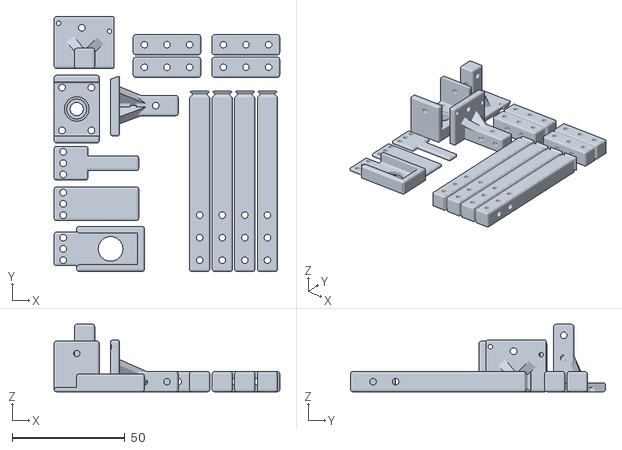
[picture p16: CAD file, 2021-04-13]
OpenSCAD/3D_Tisk/NutneMinimum.stl
100.0 x 113.0 x 30.0

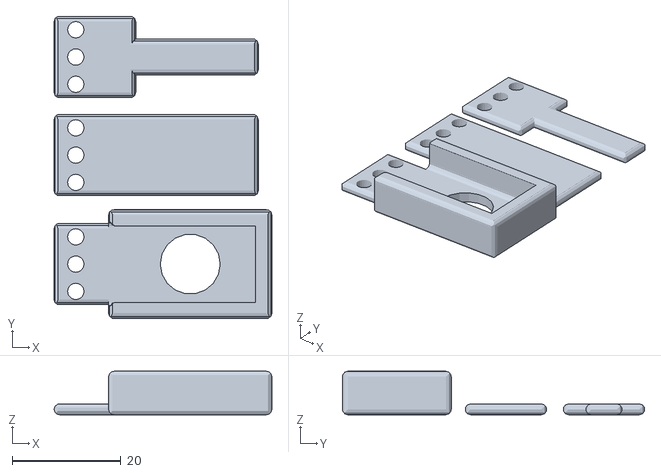
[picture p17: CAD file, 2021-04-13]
OpenSCAD/Komponenty/SenSroub.stl
40.0 x 55.5 x 8.00

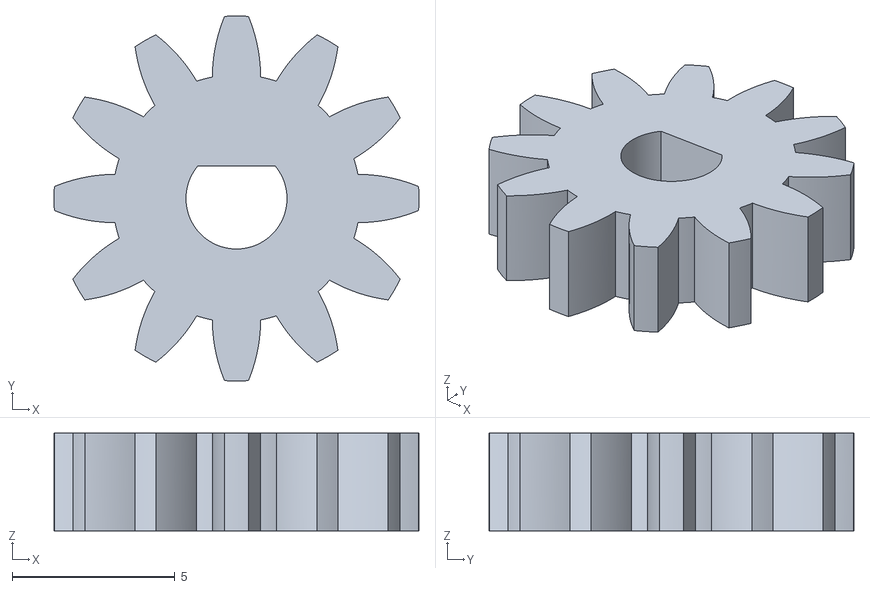
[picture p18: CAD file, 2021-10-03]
OpenSCAD/Strikackove_mechanizmus/gearmotor_pinion_12_gear_LaLaRC.stl
11.2 x 11.2 x 3.00

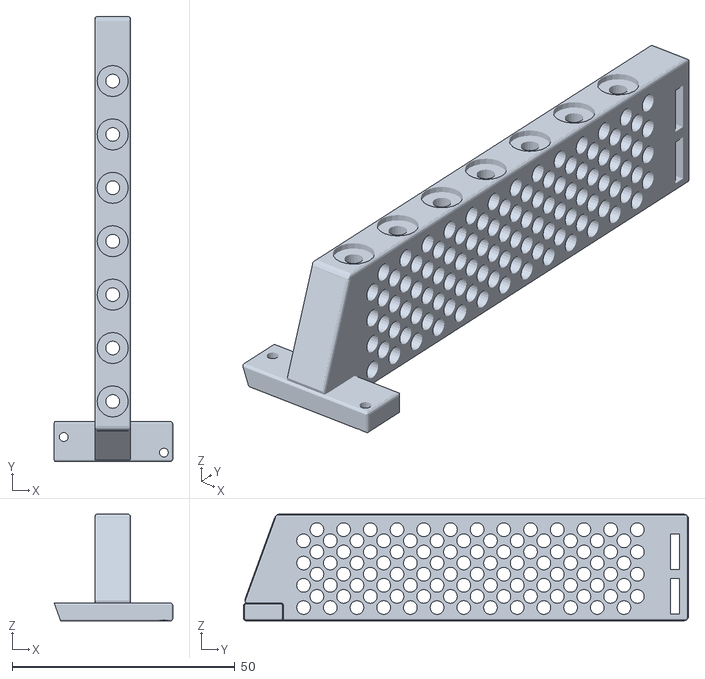
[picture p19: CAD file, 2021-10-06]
OpenSCAD/Tisk_3D_ObjektuV2a.stl
26.6 x 100.0 x 24.0

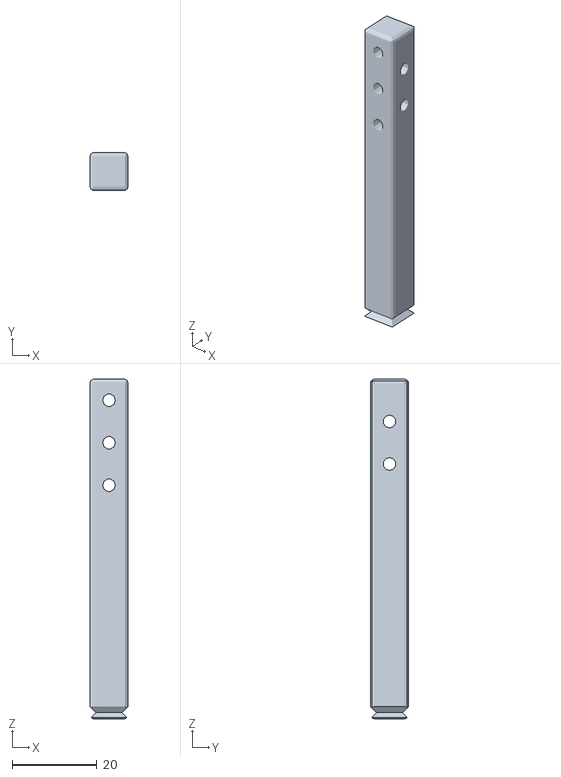
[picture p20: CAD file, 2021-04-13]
OpenSCAD/Komponenty/HranUchytSt.stl
9.00 x 9.00 x 80.0

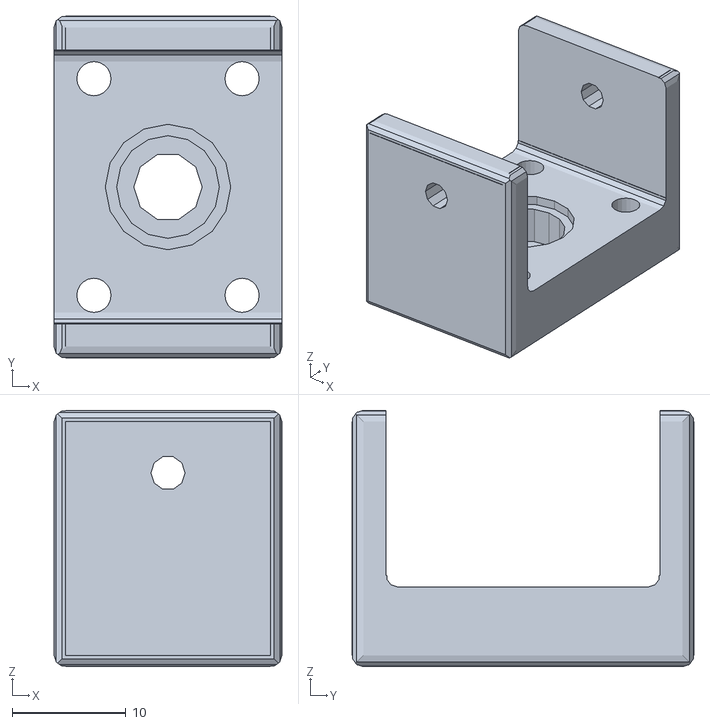
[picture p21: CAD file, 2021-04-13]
OpenSCAD/Komponenty/SenHoriz.stl
20.0 x 30.0 x 22.5

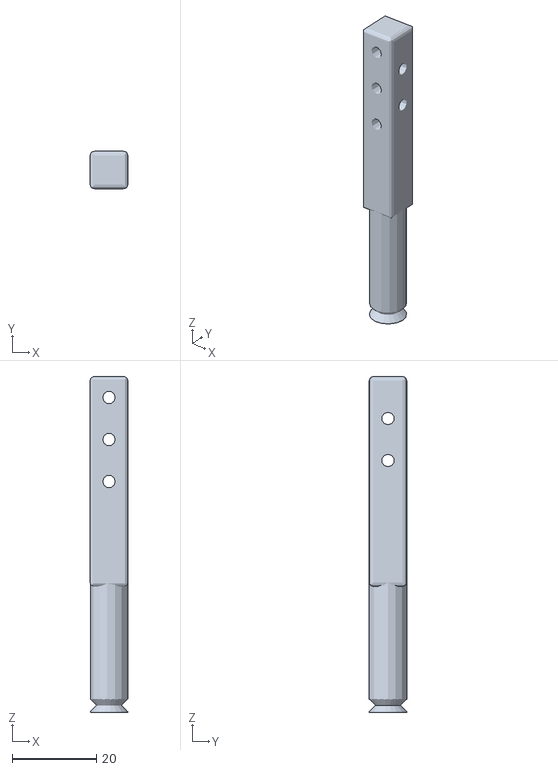
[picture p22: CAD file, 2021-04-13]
OpenSCAD/Komponenty/KulUchytSt.stl
9.00 x 9.00 x 80.0

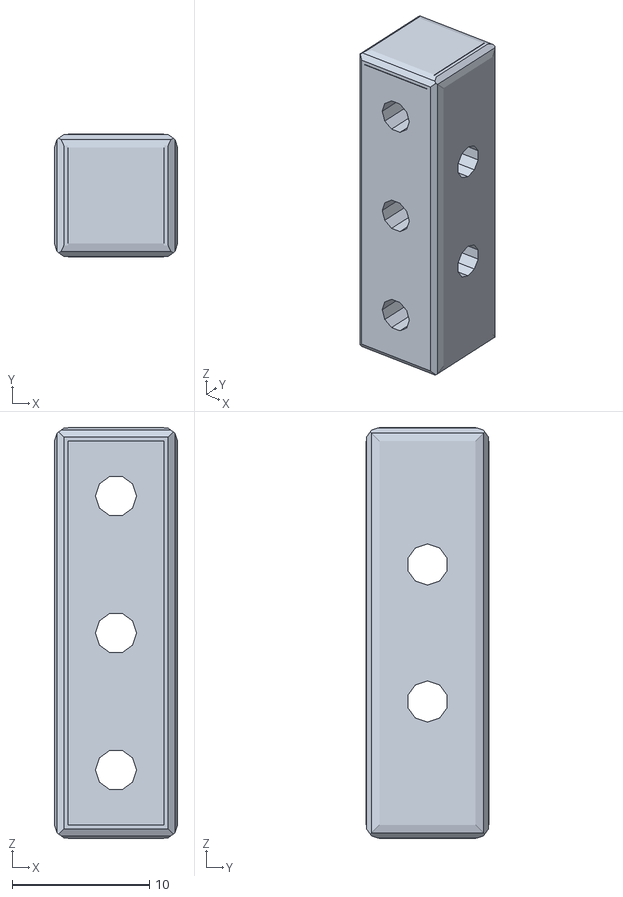
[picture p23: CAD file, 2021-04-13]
OpenSCAD/Komponenty/Spojka.stl
9.00 x 9.00 x 30.0

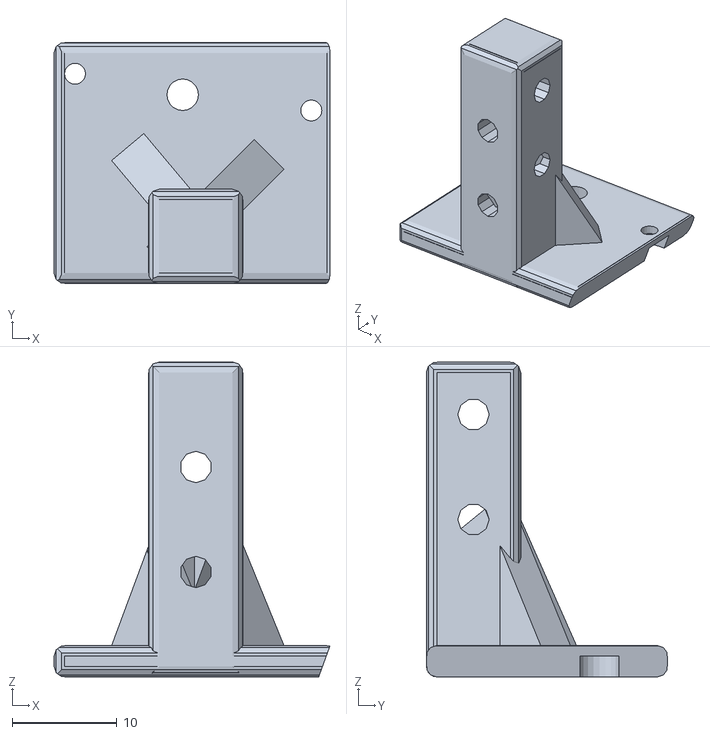
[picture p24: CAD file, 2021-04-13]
OpenSCAD/Komponenty/Nosnik_3mm.stl
26.3 x 23.0 x 30.0

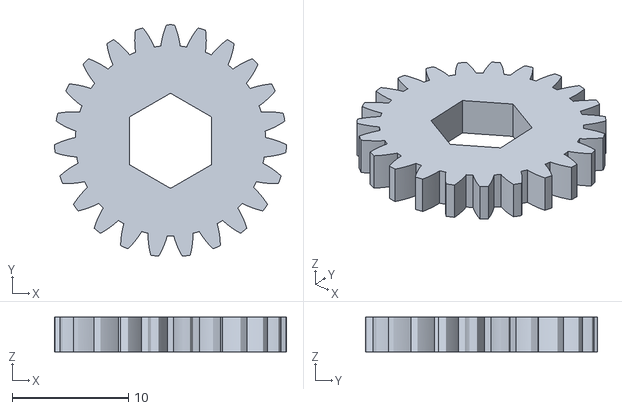
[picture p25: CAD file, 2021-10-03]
OpenSCAD/Strikackove_mechanizmus/long_bolt_gear_LaLaRC.stl
20.0 x 19.9 x 3.00

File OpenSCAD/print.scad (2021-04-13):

/*
Tento soubor je popisem komponent pomoci jazyka použivané programem OpenSCAD. https://openscad.org/

*/

TiskNutneMinimum();
module TiskNutneMinimum()//Rozložení komponent pro tisk na malé ploše. Jsou zde nutné komponenty.
{
    translate([0,0,0])SenSroub();
    translate([0,57,0])SenHoriz();
    translate([0,90,0])Nosnik();
    translate([25,60,0]) rotate([90,0,90])Nosnik();
    
    translate([90,80,0]) rotate([90,-90,0]){
    translate([0,0,0]) rotate([0,0,270]) HranUchytSt();
    translate([0,10,0]) rotate([0,0,270])HranUchytSt();
    translate([0,20,0]) rotate([0,0,270])HranUchytSt();
    translate([0,30,0]) rotate([0,0,270])HranUchytSt();
    }
    translate([100,95,0]) rotate([0,-90,0]){
    translate([0,0,0]) rotate([0,0,270]) Spojka();
    translate([0,10,0]) rotate([0,0,270])Spojka();
    translate([0,0,35]) rotate([0,0,270])Spojka();
    translate([0,10,35]) rotate([0,0,270])Spojka();
    }
}


//TiskVsechnyKomponenty();
module TiskVsechnyKomponenty()//Rozložení komponent pro tisk na větší ploše. Jsou zde všechny potřebné komponenty pro tvorbu variací komfigurace držáku plošného spoje.
{
    translate([0,0,0])SenSroub();
    translate([0,60,0])SenHoriz();
    translate([0,100,0])Nosnik();
    translate([30,100,0])Nosnik(3);
    translate([25,60,0]) rotate([90,0,90])Nosnik();
    
    translate([140,10,0]) rotate([0,-90,0]){
    translate([0,0,0])rotate([0,0,270]) KulUchytSt();
    translate([0,10,0])rotate([0,0,270]) KulUchytSt();
    translate([0,20,0])rotate([0,0,270]) KulUchytSt();
    translate([0,30,0])rotate([0,0,270]) KulUchytSt();
    }
    translate([140,50,0]) rotate([0,-90,0]){
    translate([0,0,0]) rotate([0,0,270]) HranUchytSt();
    translate([0,10,0]) rotate([0,0,270])HranUchytSt();
    translate([0,20,0]) rotate([0,0,270])HranUchytSt();
    translate([0,30,0]) rotate([0,0,270])HranUchytSt();
    }
    translate([140,90,0]) rotate([0,-90,0]){
    translate([0,0,0]) rotate([0,0,270]) Spojka();
    translate([0,10,0]) rotate([0,0,270])Spojka();
    translate([0,20,0]) rotate([0,0,270])Spojka();
    translate([0,30,0]) rotate([0,0,270])Spojka();
    }
    translate([100,82,0]) rotate([0,-90,0]){
    translate([0,0,0])  Spojka();
    translate([0,10,0]) Spojka();
    translate([0,20,0]) Spojka();
    translate([0,30,0]) Spojka();
    }
}

//SenSroub();
module SenSroub()//Jde o krabočku, kde bude umístěn malý plošný spoj, na kterém bude infračervený senzor teploty. Kraička je v plánu umýstit a upevnit na "vaničku" a to pomoci stavebnice Merkur.
{
    xO = 40;
    yO  =20;
    zO  = 8;
    zOp  = 2;
    hrana = 2;
    difference()
    {
        translate([0,0,0])
        {
        SenSroubJazik(xO,yO,zO,zOp,hrana);
            translate([10,0,0])OvalnaKrichleCisla([xO-10 ,yO ,zO],1,1,1);
        }
        translate([0,2,zOp])OvalnaKrichleCisla([xO-hrana ,yO - hrana*2 ,zO-zOp],1,1,1);
        translate([25,yO/2,0]) cylinder(10, d = 11,center  =true);
        translate([4,yO/4,0]) cylinder(10, d = 3,center  =true,$fn =20);
        translate([4,yO/2,0]) cylinder(10, d = 3,center  =true,$fn =20);
        translate([4,3*yO/4,0]) cylinder(10, d = 3,center  =true,$fn =20);
        
    }
    
    translate([0,yO,0]) SenSroubJazik(xO,yO,zO,zOp,hrana);
    translate([0,2* yO-hrana,0]) SenSroubJazikB(xO,yO,zO,zOp,hrana);
}

module SenSroubJazik(xO,yO,zO,zOp,hrana)
{
rezerva = 0.5;
    difference()
    {
        translate([0,0,0])
        {
        translate([0,hrana +rezerva ,0])OvalnaKrichleCisla([xO-rezerva-hrana ,yO-((hrana+rezerva)*2) ,zOp],1,1,1);
        }
        translate([4,yO/4,0]) cylinder(10, d = 3,center  =true,$fn =20);
        translate([4,yO/2,0]) cylinder(10, d = 3,center  =true,$fn =20);
        translate([4,3*yO/4,0]) cylinder(10, d = 3,center  =true,$fn =20);
        
    }
}

module SenSroubJazikB(xO,yO,zO,zOp,hrana)
{
rezerva = 0.5;
    difference()
    {
        translate([0,0,0])
        {
        //translate([0,hrana +rezerva ,0])OvalnaKrichleCisla([xO-rezerva-hrana ,yO-((hrana+rezerva)*2) ,zOp],1,1,1);
            translate([0,hrana +rezerva ,0])OvalnaKrichleCisla([15 ,yO-((hrana+rezerva)*2) ,zOp],1,1,1);
            translate([0,yO/3 ,0])OvalnaKrichleCisla([xO-rezerva-hrana , ,yO/3 ,zOp],1,1,1);
        }
        translate([4,yO/4,0]) cylinder(10, d = 3,center  =true,$fn =20);
        translate([4,yO/2,0]) cylinder(10, d = 3,center  =true,$fn =20);
        translate([4,3*yO/4,0]) cylinder(10, d = 3,center  =true,$fn =20);
        
    }
}


vyskaSen = 2+4+1;//globalni proměná pro výšku infračerveného senzoru
//SenHoriz();
module SenHoriz()//Jde o krabočku, kde bude umístěn malý plošný spoj, na kterém bude infračervený senzor teploty. Kraička je v plánu upevnit na tyčku vychazejicí z "Nosníku"(Popis níže).
{
    xO = 20;
    yO  =30;
    zO  = 22.5;
    difference()
   { 
       
    OvalnaKrichleCisla([xO ,yO ,zO],1,1,1);
    translate([xO/2,yO/2,0])Senzor();
    translate([-2,3,vyskaSen])OvalnaKrichleCisla([xO +4 ,yO - 6 ,zO],1,1,1);
    translate([xO/2,-1,vyskaSen  + 10,])rotate([90,0,0]) cylinder(yO  +200,d=3,$fn = 10, center = true);
       translate([3.5,5.5,0]) 
       {
           cylinder(30,d = 3, center = true,$fn =20);
        cylinder(5,d = 5, center = true,$fn =20);
       }
       translate([xO-3.5,5.5,0]) 
       {
           cylinder(30,d = 3, center = true,$fn =20);
        cylinder(5,d = 5, center = true,$fn =20);
       }
       translate([xO-3.5,yO-5.5,0]) 
       {
           cylinder(30,d = 3, center = true,$fn =20);
        cylinder(5,d = 5, center = true,$fn =20);
       }
       translate([3.5,yO-5.5,0]) 
       {
           cylinder(30,d = 3, center = true,$fn =20);
        cylinder(5,d = 5, center = true,$fn =20);
       }

   }
}


//Senzor();
module Senzor()
{
    translate([0,0,-5]) cylinder(20,d=6,$fn = 10, center = false);
    translate([0,0,2]) cylinder(20,d=9,$fn = 16, center = false);
    translate([0,0,2+4]) cylinder(20,d=11,$fn = 16, center = false);
}


//met= zkratka pro mertix sistem
metVysNosnik= 30;//globalni proměná, který určuje výšku nosníku.
//globalní proměná, která určuje výšku nástavců přidžujících plošný spoj.
metVysDrz = metVysNosnik+55+0-5; //vyskaNoisniku + vyska plošiny vdolni poleze + rezerva - 


//KulUchytSt();
module KulUchytSt()//Kulatý nastavec na držení spoje.
{
KulUchyt(metVysDrz, 30,1.5,2,9,9);
}
module KulUchyt(vyska,vyskaValce , hloubkaVyrez, pocetHranVyrezy,sirkaValce, sirkaNast = 9)
{
    translate([0,0,vyskaValce]) Nastavec(vyska-vyskaValce,5);
    translate([(sirkaNast)/2,(sirkaNast)/2,0]) difference()
    {
        cylinder(vyskaValce + 5,d = sirkaValce, center = false);
        translate([0,0,hloubkaVyrez+ 0.2])
        {
        rotate_extrude(convexity = 10) translate([sirkaValce/2, 0,0])
            //polygon( points=[[0,0],[1,1],[2,0], [0,0] );
            circle(r = hloubkaVyrez, $fn = pocetHranVyrezy *2);
        }
    }
}

//HranUchytSt();
//HranUchyt(metVysDrz);
module HranUchytSt()//Hranatý nastavec na držení spoje.
{
    HranUchyt(metVysDrz);
}


module HranUchyt(vyska, sirka = 9)
{
    difference()
    {
        Nastavec(vyska,5,sirka);
        translate([0,0,1.5])
        {
        translate([0,0,0]) rotate([0,45,0]) cube([2,30,2],center = true);
        translate([0,0,0]) rotate([0,45,90]) cube([2,30,2],center = true);
        translate([0,sirka,0]) rotate([0,45,90]) cube([2,30,2],center = true);
        translate([sirka,0,0]) rotate([0,45,00]) cube([2,30,2],center = true);
        }
    }
}

//Nosnik(3);
//Nosnik();
module Nosnik(vyskaRov = 4)// převod mezi jezdcem, který soustavu pohaní na ose z a následné konstrukce. Je nutné aby byl pevný a odolný a proto to tisknu vicekrát ze dvou pozic a dvou rozdměrů desky.
{
    deska = 9;
    odDesky = 5;
    velNast = 9;
    sirka = 27;
    translate([(sirka + velNast)/2,0,0])rotate([0,0,90]) Nastavec(30,4,velNast);
    difference()
    {
         OvalnaKrichleCisla([sirka,velNast+odDesky+deska,vyskaRov],1,1,1);
         translate([0,velNast+odDesky,0]) DiryNaDrzak();
    }
    difference()
    {
        translate([0,0,vyskaRov-4 ])
        {
    translate([13,9,0]) rotate([0,-30,130]) cube([8,4,15]);
    translate([17,6,0]) rotate([0,-30,45]) cube([8,4,15]);
        }
        translate([0,0,-10])cube([30,30,10]);
    }
}


module DiryNaDrzak()//přesne naměřeno
{
    sirkaObruby = 3.75;
    vyskaObruby = 4;
	
    translate([2,6,0]){
        cylinder(vyskaObruby,d=sirkaObruby,center=true,$fn=20);
        cylinder(10,d=2,center=true,$fn=20);
        
    }
    translate([10.75+1.5,4,0]) cylinder(10,d=3,center=true,$fn=20);
    translate([24.5,2.5,0]){
        cylinder(vyskaObruby,d=sirkaObruby,center=true,$fn=20);
        cylinder(10,d=2,center=true,$fn=20);
        translate([0,-sirkaObruby/2,-vyskaObruby/2])cube([100,sirkaObruby,vyskaObruby],center = false);
    }
    
    translate([25.2,-40,0]) rotate([0,20,0]) cube([100,100,100]);
}


//Spojka();
module Spojka()//Jde o převodnýk mezi "Nosníkem" a "Nástavci".
{
    Nastavec(5*5+5,5);
}
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

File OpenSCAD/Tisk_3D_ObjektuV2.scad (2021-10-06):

/*
Tento soubor je popisem komponent pomoci jazyka použivaného programem OpenSCAD. https://openscad.org/
*/

//3D tisk rozvržení komponentů:


//Komponenty:

//KulUchytSt();
//HranUchytSt();
//Nosnik();
//Spojka();


//met= zkratka pro mertix system
metVysNosnik= 30;//globalni proměnná, která určuje výšku nosníku.
//globalní proměnná, která určuje výšku nástavců přidržujících plošný spoj.
metVysDrz = metVysNosnik+55+0-5; //vyskaNosniku + výška plošiny v dolní poloze + rezerva - rozdíl mezi x a y tyčkou 


//KulUchytSt();
module KulUchytSt()//Kulatý nástavec na držení spoje.
{
KulUchyt(metVysDrz, 30,1.5,2,9,9);
}
module KulUchyt(vyska,vyskaValce , hloubkaVyrez, pocetHranVyrezy,sirkaValce, sirkaNast = 9)
{
    translate([0,0,vyskaValce]) Nastavec(vyska-vyskaValce,7);
    translate([(sirkaNast)/2,(sirkaNast)/2,0]) difference()
    {
        cylinder(vyskaValce + 5,d = sirkaValce, center = false);
        translate([0,0,hloubkaVyrez+ 0.2])
        {
        rotate_extrude(convexity = 10) translate([sirkaValce/2, 0,0])
            //polygon( points=[[0,0],[1,1],[2,0], [0,0] );
            circle(r = hloubkaVyrez, $fn = pocetHranVyrezy *2);
        }
    }
}

//HranUchytSt();
//HranUchyt(metVysDrz);
module HranUchytSt()//Hranatý nástavec na držení spoje.
{
    HranUchyt(metVysDrz);
}


module HranUchyt(vyska, sirka = 9)
{
    difference()
    {
        Nastavec(vyska,7,sirka);
        translate([0,0,1.5])
        {
        translate([0,0,0]) rotate([0,45,0]) cube([2,30,2],center = true);
        translate([0,0,0]) rotate([0,45,90]) cube([2,30,2],center = true);
        translate([0,sirka,0]) rotate([0,45,90]) cube([2,30,2],center = true);
        translate([sirka,0,0]) rotate([0,45,00]) cube([2,30,2],center = true);
        }
    }
}

//Nosnik(3);
//Nosnik();
module Nosnik(vyskaRov = 4)// Převod mezi pohyblivou částí CD rom a tyčkami, pomoci kterých jde nastavit šířka plošného spoje. Je nutné, aby byl Nosník pevný a odolný, a proto to tisknu vicekrát ze dvou pozic a dvou rozdměrů desky.
{
    deska = 9;
    odDesky = 5;
    velNast = 9;
    sirka = 27;
    translate([(sirka + velNast)/2,0,0])rotate([0,0,90]) Nastavec(30,4,velNast);
    difference()
    {
         OvalnaKrichleCisla([sirka,velNast+odDesky+deska,vyskaRov],1,1,1);
         translate([0,velNast+odDesky,0]) DiryNaDrzak();
    }
    difference()
    {
        translate([0,0,vyskaRov-4 ])
        {
    translate([13,9,0]) rotate([0,-30,130]) cube([8,4,15]);
    translate([17,6,0]) rotate([0,-30,45]) cube([8,4,15]);
        }
        translate([0,0,-10])cube([30,30,10]);
    }
}


NosnikV2();
module NosnikV2(vyskaRov = 4, delkaRov = 100)// Převod mezi pohyblivou částí CD rom a tyčkami, pomoci kterých jde nastavit šířka plošného spoje. Je nutné, aby byl Nosník pevný a odolný, a proto to tisknu vicekrát ze dvou pozic a dvou rozdměrů desky.
{
    deska = 9;
    odDesky = 5;
    velNast = 8;
    sirka = 27;
    delkaNavic = 1;
    vyskaNast = 24;
    diryRozdm = 3.1;
    diryStart = (velNast+delkaNavic+(3/2)+3);
    diryKrok = 3*2;//diryRozdm*2;
    diryStop = (delkaRov - (3/2)-10);
    
    translate([0,0,0]) difference()
    {
    translate([0,0,0])
        {
    translate([(sirka-velNast)/2,0,vyskaRov]) rotate([-20,0,0]) OvalnaKrichleCisla([velNast,10,vyskaNast-2.8],1,0.5,0.5);
            
    translate([(sirka-velNast)/2,7,0]) OvalnaKrichleCisla([velNast,delkaRov-7,vyskaNast],1,0.5,0.5);
            
            
        }
        for(i=[diryStart:diryKrok:diryStop])
        {
            translate([0,i,3]) rotate([0,90,0]) cylinder(sirka, d = diryRozdm, true,$fn=20);
            translate([0,i,13]) rotate([0,90,0]) cylinder(sirka, d = diryRozdm, true,$fn=20);
            translate([0,i,8]) rotate([0,90,0]) cylinder(sirka, d = diryRozdm, true,$fn=20);
            translate([0,i,18]) rotate([0,90,0]) cylinder(sirka, d = diryRozdm, true,$fn=20);
            
            translate([0,3,2.5]){
            translate([0,i,3]) rotate([0,90,0]) cylinder(sirka, d = diryRozdm, true,$fn=20);
            translate([0,i,13]) rotate([0,90,0]) cylinder(sirka, d = diryRozdm, true,$fn=20);
            translate([0,i,8]) rotate([0,90,0]) cylinder(sirka, d = diryRozdm, true,$fn=20);
            translate([0,i,18]) rotate([0,90,0]) cylinder(sirka, d = diryRozdm, true,$fn=20);
            }
            
            translate([0,0,2.5]){
            translate([(sirka)/2,delkaRov-17,3]) rotate([-90,0,0]) cylinder(20, d = diryRozdm, true,$fn=20);
                //translate([(sirka)/2,delkaRov-20,8]) rotate([-90,0,0]) cylinder(20, d = diryRozdm, true,$fn=20);
                translate([(sirka)/2,delkaRov-17,13]) rotate([-90,0,0]) cylinder(20, d = diryRozdm, true,$fn=20);
            translate([(sirka-velNast)/2,delkaRov-2-2,0-1]) cube([velNast,2,8]);
            translate([(sirka-velNast)/2,delkaRov-2-2,10-1]) cube([velNast,2,8]);
            }
            ///translate([(sirka-velNast)/2,delkaRov-2-2,2]) cube([velNast,2,7]);
            //translate([(sirka-velNast)/2,delkaRov-2-2,]) cube([velNast,2,7]);
            
        }
        
        for(i=[diryStart:diryKrok*2:diryStop])
        {
            translate([sirka/2,i,0]) cylinder(sirka, d = diryRozdm, true,$fn=20);
            translate([sirka/2,i,vyskaNast-1]) cylinder(sirka, d = 7, true,$fn=20);
        }
        
        
        
        
        
    }
        translate([sirka,+delkaNavic + velNast,0]) rotate([0,0,180])difference()
    {
         OvalnaKrichleCisla([sirka,velNast+delkaNavic,vyskaRov],0.5,0.5,0.5);
         translate([0,delkaNavic,0]) DiryNaDrzak();
    }
    }


module DiryNaDrzak()//přesně naměřeno
{
    sirkaObruby = 3.75;
    vyskaObruby = 4;
	
    translate([2,6,0]){
        cylinder(vyskaObruby,d=sirkaObruby,center=true,$fn=20);
        cylinder(10,d=2,center=true,$fn=20);
        
    }
    //translate([10.75+1.5,4,0]) cylinder(10,d=3,center=true,$fn=20);
    translate([24.5,2.5,0]){
        cylinder(vyskaObruby,d=sirkaObruby,center=true,$fn=20);
        cylinder(10,d=2,center=true,$fn=20);
        translate([0,-sirkaObruby/2,-vyskaObruby/2])cube([100,sirkaObruby,vyskaObruby],center = false);
    }
    
    translate([25.2,-40,0]) rotate([0,20,0]) cube([100,100,100]);
}


//Spojka();
module Spojka()//Jde o převodník mezi "Nosníkem" a "Nástavci".
{
    Nastavec(5*5+5,5);
}


//Univerzálni nástavec
module Nastavec(vyska,pocetDer,sirka = 9)
{
    //OvalnaKrichleCisla([10,10,vyska],1,1,1);
    difference()
    {
        
        OvalnaKrichleCisla([sirka ,sirka ,vyska],1,1,1);
        translate([0,0,2.5])
        {
            for(i = [0 : 1: pocetDer-1])
            {

            translate([sirka/2,sirka/2,vyska - 5-i*5]) rotate([0,90,0]) cylinder(h=sirka*2,d = 3.1,center = true,$fn=20);
            translate([sirka/2,sirka/2,vyska - 7.5-i*5]) rotate([90,0,0]) cylinder(h=sirka*2,d = 3.1,center = true,$fn=20);
                
            }
        }
    }
}


//Kód pro vytvoření oválných kvádrů
module OvalnaKrichleX(Rozdmery, zakulaceni)
{
	union() {
	translate([0,zakulaceni,0]) cube([Rozdmery[0],Rozdmery[1] - zakulaceni * 2,Rozdmery[2]],center=false);
	translate([0,0,zakulaceni]) cube([Rozdmery[0],Rozdmery[1],Rozdmery[2] - zakulaceni * 2],center=false);
	translate([0,zakulaceni,zakulaceni]) rotate([0,90,0]) cylinder( Rozdmery[0],   zakulaceni, zakulaceni,false,$fn=10);
	translate([0,Rozdmery[1] - zakulaceni,zakulaceni]) rotate([0,90,0]) cylinder( Rozdmery[0],   zakulaceni, zakulaceni,false,$fn=10);
	translate([0,zakulaceni,Rozdmery[2] - zakulaceni]) rotate([0,90,0]) cylinder( Rozdmery[0],   zakulaceni, zakulaceni,false,$fn=10);
	translate([0,Rozdmery[1] - zakulaceni,Rozdmery[2] - zakulaceni]) rotate([0,90,0]) cylinder( Rozdmery[0],   zakulaceni, zakulaceni,false,$fn=10);
	}
}


module OvalnaKrichleY(Rozdmery, zakulaceni)
{
	union() {
	translate([zakulaceni,0,0]) cube([Rozdmery[0] - zakulaceni * 2,Rozdmery[1],Rozdmery[2]],center=false);
	translate([0,0,zakulaceni]) cube([Rozdmery[0],Rozdmery[1],Rozdmery[2] - zakulaceni * 2],center=false);
	translate([zakulaceni,0,zakulaceni]) rotate([270,0,0]) cylinder( Rozdmery[1],   zakulaceni, zakulaceni,false,$fn=10);
	translate([Rozdmery[0] - zakulaceni,0,zakulaceni]) rotate([270,0,0]) cylinder( Rozdmery[1],   zakulaceni, zakulaceni,false,$fn=10);
	translate([zakulaceni,0,Rozdmery[2] - zakulaceni]) rotate([270,0,0]) cylinder( Rozdmery[1],   zakulaceni, zakulaceni,false,$fn=10);
	translate([Rozdmery[0] - zakulaceni,0,Rozdmery[2] - zakulaceni]) rotate([270,0,0]) cylinder( Rozdmery[1],   zakulaceni, zakulaceni,false,$fn=10);
	}
}
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

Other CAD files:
OpenSCAD/Tisk_3D_Objektu.scad

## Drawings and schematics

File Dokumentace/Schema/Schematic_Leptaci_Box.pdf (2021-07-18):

# Arduino Nano RST 31 SCK 32 SO ³³ GND ³⁴ SI 35 5V 36 Digital (PWM ~⁾ Anal gico USB 37

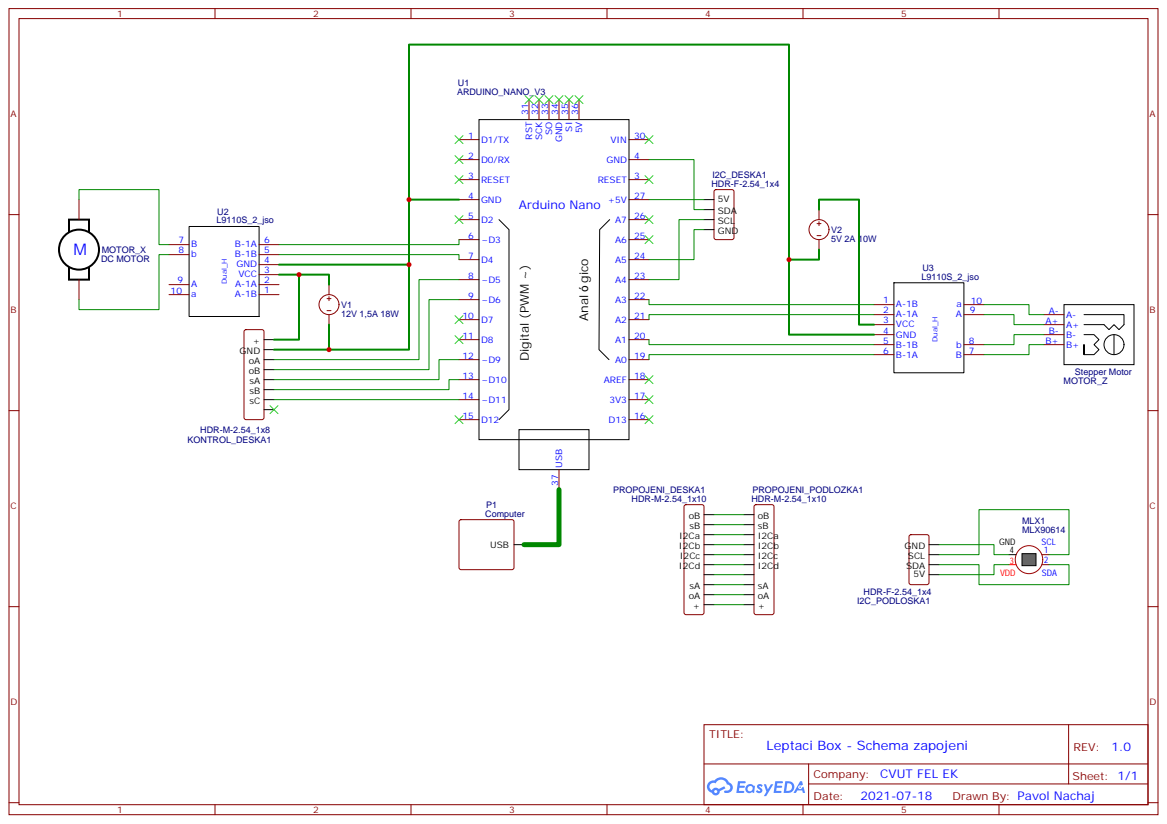
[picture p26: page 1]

Company: CVUT FEL EK

Drawn By: Pavol Nachaj

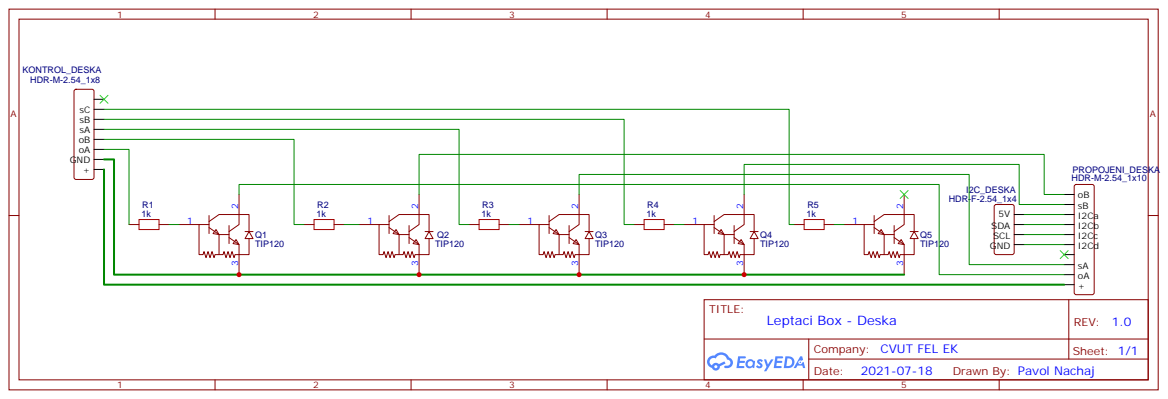
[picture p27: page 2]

Company: CVUT FEL EK

Drawn By: Pavol Nachaj

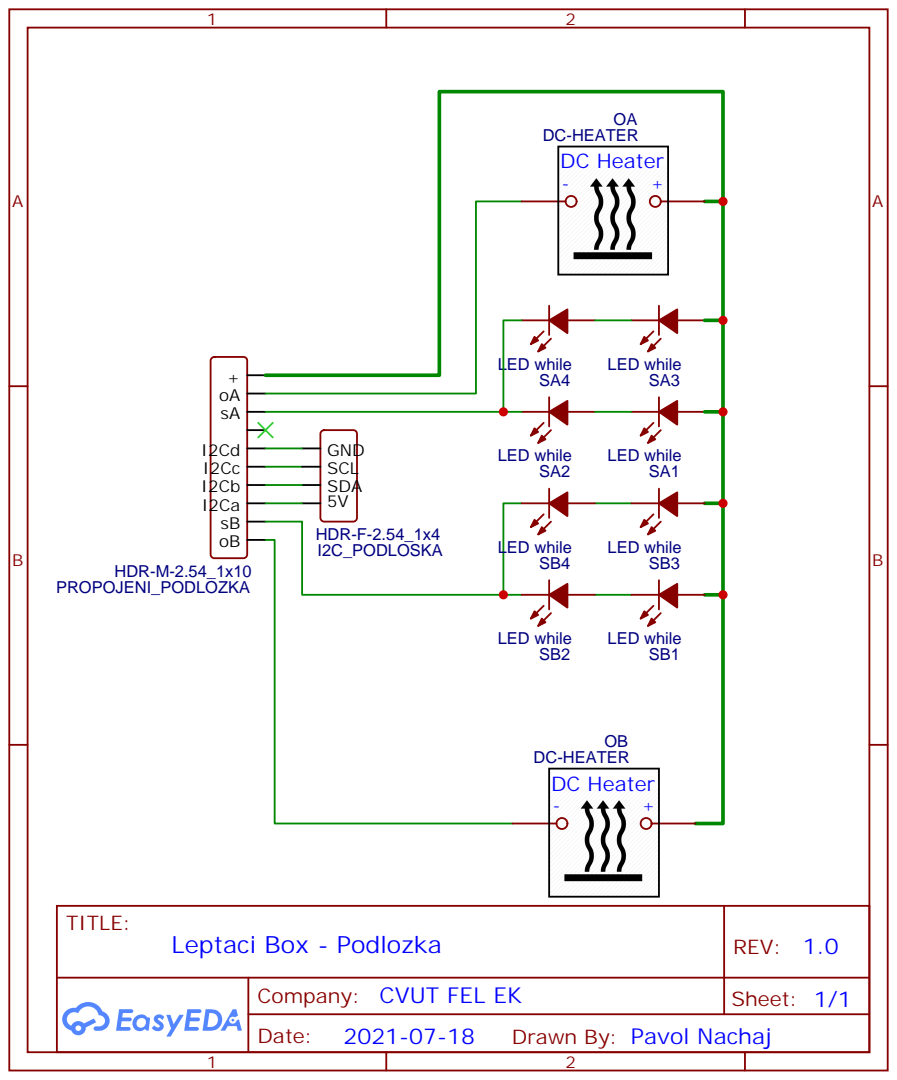
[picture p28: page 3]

Company: CVUT FEL EK

Drawn By: Pavol Nachaj

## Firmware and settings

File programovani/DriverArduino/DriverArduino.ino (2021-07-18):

/*
Program pro Arduino Nano.
Arduino je uvnitr Leptaciho boxu, kde zastava funkci microkontroleru.


*/
#include <Arduino.h>
#include <avr/wdt.h>
#include <Wire.h>
#include <Adafruit_MLX90614.h>
#include "definice.h"//Spolecny soubor pro Aplikaci

//Seznam zapojenych pinu:
#define pinOhrevA 5
#define pinOhrevB 6
#define pinSvetloA 9
#define pinSvetloB 10
#define pinSvetloC 11
#define pinMotorXpwm 3
#define pinMotorXdig 4
#define pinMotorZ1 17
#define pinMotorZ2 16
#define pinMotorZ3 15
#define pinMotorZ4 14
//piny, ktere jsou nastaveny jinak nez pres pinMode(...)
#define pinTepSCL 19
#define pinTepSDA 18
#define pinSerTX 1
#define pinSerRX 0

// inicializace teploměru MLX z knihovny
Adafruit_MLX90614 mlx = Adafruit_MLX90614();


//Globalni promenne
char mode;//instrukce
// default String
String value = String(PrazdnePole);//Pouzivan jako predavac informace o datech v instrukci.
// inicializace globalnich promennych
dtOhrev ohrevA;
dtOhrev ohrevB;
dtSvetlo svetloA;
dtSvetlo svetloB;
dtSvetlo svetloC;
dtMotorX motorX;
dtMotorZ motorZ;

//promenne motoruZ
int motorZscit;//urcuje smer pohybu pri vibracich
byte motorZkrok;//Krok motoru Z
const bool motorZMetrix[5][4]= {{1,0,1,0},{0,1,1,0},{0,1,0,1},{1,0,0,1},{0,0,0,0}};//vystupy pinu vuci krokum
long long motorZtime;//cas dalsiho kroku

void setup() 
{
  Serial.begin(9600);// inicializace UART
  Serial.flush();
  mlx.begin(); // inicializace teploměru MLX z knihovny

  //Nastaveni pinu
  pinMode(pinOhrevA, OUTPUT);
  pinMode(pinOhrevB, OUTPUT);
  pinMode(pinSvetloA , OUTPUT);
  pinMode(pinSvetloB , OUTPUT);
  pinMode(pinSvetloC , OUTPUT);
  pinMode(pinMotorXpwm , OUTPUT);
  pinMode(pinMotorXdig , OUTPUT);
  pinMode(pinMotorZ1 , OUTPUT);
  pinMode(pinMotorZ2 , OUTPUT);
  pinMode(pinMotorZ3 , OUTPUT);
  pinMode(pinMotorZ4 , OUTPUT);

  //Inicializace promennych
  //Ohrev: Aktivni vyuziti, rozsah 0-255
  ohrevA = 0;
  ohrevB = 0;
  //Svetlo: Aktivni vyuziti, rozsah 0-255
  svetloA = 0;
  svetloB =0;
  svetloC =0;
  //MotorX: default:0
  motorX = 0;
  //Svetlo: Aktivni vyuziti, prepinani mezi 0 (stopMotorZ) a 3 (vibMotorZOn)
  motorZ = 0;
  //Systemove promenne pro motor X
  motorZkrok=0;
  motorZtime=0;
}


void loop() {
  if(Serial.available() >= 6)//detekce instrukce
  {
    mode = Serial.read();//Nacteni modu
    //nacteni dat
    value.setCharAt(0,Serial.read());
    value.setCharAt(1,Serial.read());
    value.setCharAt(2,Serial.read());
    value.setCharAt(3,Serial.read());
    //nacteni koncoveho znaku
    Serial.read();

    //Vykonani prikazu
    switch(mode)
    {
      case modOhrevA:
      Ohrev(mode,&ohrevA,pinOhrevA);
      break;
      case modOhrevB:
      Ohrev(mode,&ohrevB,pinOhrevB);
      break;
      case modSvetloA:
      Svetlo(mode,&svetloA,pinSvetloA)  ;
      break;
      case modSvetloB:
      Svetlo(mode,&svetloB,pinSvetloB)  ;
      break;
      case modSvetloC:
      Svetlo(mode,&svetloC,pinSvetloC)  ;
      break;    
      case modMotorX:
      MotorXB()  ;
      break; 
      case modMotorZ:
      MotorZ()  ;
      break; 
      case modTepNadrz:
      TepNadrzB();
      break;
      case modTepOkoli:
      TepOkoliB();
      break;
      case modIdentifikace:
      Identifikace();
      break;
      default:
      Serial.print(Problem);
      break;
    }
  }
  MotorZrun();//Rutina vytvarejici vibrace u motoru Z
}


void Ohrev(char mod,dtOhrev *data, int pin)//Metoda pro zpracovani instukce Ohrev
{
  if(notSend(mod,*data))
  {
  *data = value.toInt();
   analogWrite(pin, *data);
  }
}


void Svetlo(char mod,dtSvetlo *data, int pin)//Metoda pro zpracovani instukce Svetlo
{
  if(notSend(mod,*data))
  {
  *data = value.toInt();
   analogWrite(pin, *data);
  }
}


//Metoda pro zpracovani instukce MotorX.
/*
PWM rizeni nezvladal zdroj 12V nebo H-mustkem. 
Proto jsem pristoupil na binarni rizeni, ktere je ovsem velmi rychle a silne.
Kvuli moznosti poskozeni o stenu jsem urcil casovy limit pri posunech.
Funkce vyckava, dokud cas nevyprsi. 
Prikaz stopMotorX nema zadnou funkci
Omezuje to motor Z pri vibracich, co nicemu nevadi.
Omezeje zpracovavani novych instukci na max 200ms, co nevadi.
*/
void MotorXB()
{
  if(notSend(modMotorX,motorX))
  {
    dtMotorX novi = value.toInt();
    if(novi == levoSMotorX )
    {
      digitalWrite(pinMotorXdig, 0);
      digitalWrite(pinMotorXpwm, 1);
      delay(50);
    }
    else if(novi == levoBMotorX)
    {
      digitalWrite(pinMotorXdig, 0);
      digitalWrite(pinMotorXpwm, 1);
      delay(200);
    }
    else if(novi == pravSMotorX)
    {
      digitalWrite(pinMotorXdig, 1);
      digitalWrite(pinMotorXpwm, 0);
      delay(50);
    }
    else if(novi == pravBMotorX)
    {
      digitalWrite(pinMotorXdig, 1);
      digitalWrite(pinMotorXpwm, 0);
      delay(200);
    }
    //vypnuti motoru
    digitalWrite(pinMotorXdig, 0);
    digitalWrite(pinMotorXpwm, 0);
  }
}


void TepOkoliB()//Posle udaj o teplote v Leptacim boxu.
{
  notSend(modTepOkoli,TepControl(mlx.readAmbientTempC()));
}


void TepNadrzB()//Posle udaj o teplote miskyA.
{
  notSend(modTepNadrz,TepControl(mlx.readObjectTempC()));
}

void Identifikace()//Odpoved na dotaz identifikace
{
  notSend(modIdentifikace,numIdentifikace);
}

int TepControl(dtTep a)//kontrola chyb teplomeru a uprava formatu
{
  int u=(double)(a*tepNas);
  if(u<minTep*tepNas) {u = minTep*tepNas;}
  if(u>maxTep*tepNas) {u = maxTep*tepNas;}
  return u;
}


/*
Metoda MotorZ() ma dva rozdilne zamereni
-Posunuje o predem difinovany pocet kroku motor Z. Po tuto dobu zastaveno zpracovani novych instrukci.
--Nefunkguje prikaz stopMotorZ
-Nastavy MotorZrun() na generator vibraci (vibMotorZOn) nebo vibrace vypne (stopMotorZ).
*/
void MotorZ()
{
  if(notSend(modMotorZ,motorZ))
  {
    dtMotorZ novi = value.toInt();
    if(novi == stopMotorZ )
    {
       motorZkrok = 4;
       motorZ = stopMotorZ;
       MotorZindex(4);
    }
    else if(novi == nahorumotorZ)
    {
      for(int i = 0; i <= 32;  i++)
      {
        MotorZindex(i%4);
        delay(7);
      }
    } 
    else if(novi == dolumotorZ)
    {
      for(int i = 32; i >=0;  i--)
      {
        MotorZindex(i%4);
        delay(10);
      }
    }  
    else if(novi == vibMotorZOn)
    {
       motorZkrok = 0;
       motorZ = vibMotorZOn;
       motorZtime = millis();
       motorZscit = 1;
    }
    MotorZindex(4);
  }
}


void MotorZrun()//Tento kod je spousten v loop(). Pokud jsou splneny podminky, vitvari vibrace
{
  if(motorZ == vibMotorZOn && motorZtime < millis())
  {
    MotorZindex(motorZkrok);
    motorZtime = millis() + 10;
    if(motorZkrok == 3)
    {
      motorZscit = -1;
    }
    else if(motorZkrok == 0)
    {
      motorZscit = 1;
    }
    motorZkrok += motorZscit;
  }
}


void MotorZindex(int index)//Nastaveni pinu u motoru Z.
{
    digitalWrite(pinMotorZ1, motorZMetrix[index][0]);
    digitalWrite(pinMotorZ2, motorZMetrix[index][1]);
    digitalWrite(pinMotorZ3, motorZMetrix[index][2]);
    digitalWrite(pinMotorZ4, motorZMetrix[index][3]);
}


//Return je:
//True:  Nenalezeno "????" a pokracuje se dal v ukonech jako zapsani dat.
//False: Nalezeno "????" a zpracovano. Zakaz delat dalsi ukony.
bool notSend(char typ, int data)
{
  //Za predpokladu, ze se ve value nachazi bud ctyrmistne cislo nebo "????", neni potreba pro '?' hldedat v kazdem ze ctyr pozic.
  if(value.charAt(2) == '?')
  {
  char c[6];
  sprintf(c, "%c%4d\n", typ,data);
  Serial.print(c);
  return false;
  } 
  return true;
}

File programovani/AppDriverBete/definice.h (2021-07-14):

/*
Tento soubor je totozny s:
-programovani/AppDriverBete/definice.h
-programovani/DriverArduino/definice.h
Kvuli kompaktibilite komunikacniho protokolu.
Ano, nesystemovost nazvu vypliva z historie projektu. 
Bylo by velmi neprakticke prejmenovavat definice v projektu Arduino, tak v App.

*/
#define modOhrevA 'A'
#define modOhrevB 'B'
#define modSvetloA 'C'
#define modSvetloB 'D'
#define modSvetloC 'E'
#define modMotorX 'F'
#define modMotorZ 'G'
#define modTepNadrz 'H'
#define modTepOkoli 'I'
#define modIdentifikace 'L'

#define numIdentifikace 1234

#define dtOhrev uint8_t
#define dtSvetlo uint8_t
#define dtMotorX int16_t
#define dtMotorZ int8_t
#define dtTep double

#define tepNas 100.0

#define maxTep 99.0
#define maxSvetlo 255
#define maxOhrev 255
#define minTep 20.0
#define minSvetlo 0
#define minOhrev 0

#define levoSMotorX 1
#define levoBMotorX 2
#define pravSMotorX 3
#define pravBMotorX 4

#define vibMotorZOn 3
#define stopMotorZ 0
#define stopMotorX 0

#define nahorumotorZ 2
#define dolumotorZ 1

#define Dotaz "????"
#define PrazdnePole "0000"
#define Problem "eeee"

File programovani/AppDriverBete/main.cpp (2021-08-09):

//include knihoven
#include <QApplication>
#include <QDebug>
#include <QSerialPort>
#include <QSerialPortInfo>
#include <QComboBox>
#include <QLabel>
#include <QPushButton>
#include <QHBoxLayout>
#include <QVBoxLayout>
#include <QSlider>
#include <QString>
#include <QByteArray>
#include <QObject>
#include <QFont>
#include <QTimer>
#include <QGridLayout>
#include <QFrame>
#include <QLCDNumber>
#include <QThread> 
#include <QDoubleSpinBox>

//inicializace souboru...
#include "definice.h"//Spolecny soubor pro Arduino
#include "protokolKomunikace.h"//komunikacni protokol
#include "qcustomplot.h"//graf
//#include "prepravaDat.h"



//main
int main(int argc, char ** argv)
{

	
	QApplication a(argc, argv);
	QTimer timerAkt1 ;//pravidelna aktualizace dat
	QList<QSerialPortInfo> seznamPort = QSerialPortInfo::availablePorts();//seznam vsech portu v PC
	QSerialPortInfo vybranyPort;//Port na kterem je Leptaci box
	QSerialPort serialovyPort;//inicializace vybraneho portu
	QWidget w;
	QVBoxLayout vbox;
	//Oblasti grafiky
	QHBoxLayout potrSerialSetBox;//nastaveni portu
	QHBoxLayout potrSerialSetBox2;//nastaveni portu text
	QGridLayout joystick;//ovladani motoru X a Z
	QHBoxLayout aktVseBox;//Tlacitko Aktualizovat vse
	QHBoxLayout miskaABox;//Oblast Misky A
	QHBoxLayout miskaBBox;//Oblast Misky B
	QHBoxLayout svetloABox;//kontrola osvetleni misky A
	QHBoxLayout svetloBBox;//kontrola osvetleni misky B
	QHBoxLayout teplotaABox;//kontrola ohrevu misky A
	QHBoxLayout teplotaAGrafBox;//Texty k grafu
	QVBoxLayout teplotaAGrafBox2;//grafu
	QHBoxLayout ohrevABox;//kontrola teploty misky A
	QHBoxLayout ohrevBBox;//kontrola teploty misky B
	QHBoxLayout vnijsiTeplotaBox;//teplota v Leptacim boxu

	
	//font pro indikaci Ohrivani
	QFont fOhrev = QFont("Arial", 20, QFont::Bold);
	//font pro Nadpisy
	QFont fNadpis = QFont("Arial", 15, QFont::Bold);
	//Horizontalni cary
	QFrame oddelPort(&w);
	oddelPort.setFrameStyle( QFrame::HLine | QFrame::Plain);
	QFrame oddelMotor(&w);
	oddelMotor.setFrameStyle( QFrame::HLine | QFrame::Plain);
	QFrame oddelMiskaA(&w);
	oddelMiskaA.setFrameStyle( QFrame::HLine | QFrame::Plain);
	QFrame oddelMiskaB(&w);
	oddelMiskaB.setFrameStyle( QFrame::HLine | QFrame::Plain);



	//Nastaveni portu
	QLabel potrSerialSetBoxText("Vyber portu:",&w),potrSerialSetBoxTextStatus("Stav: ",&w),potrSerialSetBoxStatus("Nebyl vybran zadny port.",&w);
	potrSerialSetBoxText.setFont(fNadpis);
	QPushButton potrSerialSetBoxButAkt("Aktualizovat seznam");
	QComboBox potrSerialSetBoxCombSeznamPortu(&w);
	auto infos = QSerialPortInfo::availablePorts();
    for (QSerialPortInfo &info : infos)
	{
        potrSerialSetBoxCombSeznamPortu.addItem(info.portName());//vypis portu do Combo
	}

	QPushButton potrSerialSetBoxButOk("Vyber");//Vyber portu
	
	potrSerialSetBox.addWidget(&potrSerialSetBoxText);
	potrSerialSetBox.addWidget(&potrSerialSetBoxButAkt);
	potrSerialSetBox.addWidget(&potrSerialSetBoxCombSeznamPortu);
	potrSerialSetBox.addWidget(&potrSerialSetBoxButOk);
	potrSerialSetBox2.addWidget(&potrSerialSetBoxTextStatus);
	potrSerialSetBox2.addWidget(&potrSerialSetBoxStatus);
	//potrSerialSetBox.addWidget(&potrSerialSetBoxButAnswerAll);


	QPushButton BoxButAnswerAll("Aktualizovat vsechny data");//Aktualizuje vsechny data
	aktVseBox.addWidget(&BoxButAnswerAll);

	//Text k motorum
	QLabel motorBoxText("Joysticky pro ovladani ramene:",&w);
	motorBoxText.setFont(fNadpis);

	//Rizeni Motoru X
	QPushButton motorXBoxLeftB("<<"),motorXBoxLeftS("<"),motorXBoxRightS(">"),motorXBoxRightB(">>");

	
	//Rizeni Motoru Z
	QPushButton motorZBoxUp("Nahoru"), motorZBoxDown("Dolu"), motorZBoxStop_Vibration("Vibrace");
	dtMotorZ mZ;
	QString motorZBoxtextVibrace = QString("Vibrace");
    QString motorZBoxtextStop = QString("Stop");

	
	joystick.addWidget(&motorZBoxUp, 0,2);
	joystick.addWidget(&motorZBoxStop_Vibration, 1,2);
	joystick.addWidget(&motorZBoxDown, 2,2);
	joystick.addWidget(&motorXBoxLeftB, 1,0);
	joystick.addWidget(&motorXBoxLeftS, 1,1);
	joystick.addWidget(&motorXBoxRightS, 1,3);
	joystick.addWidget(&motorXBoxRightB, 1,4);


	//miska A s nastavenim regulace ohrevu misky A
	QLabel miskaABoxText("Miska A:",&w),miskaABoxMaxTepText("Nastav maximalni teplotu:",&w);
	QDoubleSpinBox miskaABoxMaxSpin(&w);
	miskaABoxMaxSpin.setRange(minTep,maxTep);
	miskaABoxMaxSpin.setStyleSheet("background-color: white;");
	miskaABoxMaxSpin.setValue(40.0);
	miskaABoxText.setFont(fNadpis);
	QPushButton miskaABoxAnswer("Aktualizace");
	miskaABox.addWidget(&miskaABoxText);
	miskaABox.addWidget(&miskaABoxAnswer);
	miskaABox.addWidget(&miskaABoxMaxTepText);
	miskaABox.addWidget(&miskaABoxMaxSpin);


	//Regulace podsviceni
	QLabel svetloABoxText("Regulace podsviceni",&w);
	QSlider svetloABoxSlider( Qt::Horizontal,&w);
	svetloABoxSlider.setMaximum(100);
	svetloABoxSlider.setMinimum(0);
	svetloABoxSlider.setPageStep(1);
	svetloABoxSlider.setSingleStep(1);

	svetloABox.addWidget(&svetloABoxText);
	svetloABox.addWidget(&svetloABoxSlider);


	//Indikace teploty misky
	QLCDNumber teplotaABoxIndikatorTeploty(7,&w);
	teplotaABoxIndikatorTeploty.setSegmentStyle(QLCDNumber::Flat);
	teplotaABoxIndikatorTeploty.setMinimumHeight(100);
	teplotaABoxIndikatorTeploty.setFixedWidth(400);
	QLabel teplotaABoxName("Teplota: ",&w); 
	teplotaABox.addWidget(&teplotaABoxName);
	teplotaABox.addWidget(&teplotaABoxIndikatorTeploty);
	


	//Regulace ohrevu misky
	QLabel ohrevABoxText("Ohrev: "), ohrevABoxStav("??????");
	ohrevABoxStav.setFont(fOhrev);
	ohrevABoxStav.setMinimumWidth(200);
	QSlider ohrevABoxSlider(Qt::Horizontal,&w);
	ohrevABoxSlider.setMaximum(255);
	ohrevABoxSlider.setMinimum(0);
	ohrevABoxSlider.setPageStep(1);
	ohrevABoxSlider.setSingleStep(1);

	ohrevABox.addWidget(&ohrevABoxText);
	ohrevABox.addWidget(&ohrevABoxSlider);
	ohrevABox.addWidget(&ohrevABoxStav);


	//miska B
	QLabel miskaBBoxText("Miska B:",&w);
	miskaBBoxText.setFont(fNadpis);
	QPushButton miskaBBoxAnswer("Aktualizace");
	miskaBBox.addWidget(&miskaBBoxText);
	miskaBBox.addWidget(&miskaBBoxAnswer);


	//Regulace podsviceni
	QLabel svetloBBoxText("Regulace podsviceni",&w);
	QSlider svetloBBoxSlider( Qt::Horizontal,&w);	
	svetloBBoxSlider.setMaximum(100);
	svetloBBoxSlider.setMinimum(0);
	svetloBBoxSlider.setPageStep(1);
	svetloBBoxSlider.setSingleStep(1);

	svetloBBox.addWidget(&svetloBBoxText);
	svetloBBox.addWidget(&svetloBBoxSlider);


	//Indikace teploty nadrze B neni


	//Regulace ohrevu misky
	QLabel ohrevBBoxText("Ohrev: "), ohrevBBoxStav("??????");
	ohrevBBoxStav.setFont(fOhrev);
	ohrevBBoxStav.setMinimumWidth(200);
	QSlider ohrevBBoxSlider(Qt::Horizontal,&w);
	ohrevBBoxSlider.setMaximum(255);
	ohrevBBoxSlider.setMinimum(0);
	ohrevBBoxSlider.setPageStep(1);
	ohrevBBoxSlider.setSingleStep(1);

	ohrevBBox.addWidget(&ohrevBBoxText);
	ohrevBBox.addWidget(&ohrevBBoxSlider);
	ohrevBBox.addWidget(&ohrevBBoxStav);
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

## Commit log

2021-04-07 Pridan souboru pro 3D tisk
    [print.scad]
2021-04-13 Aktualizace 3D objekru
    [print.scad]
2021-04-13 Nahrani 3D modelu
    [HranUchytSt.stl, KulUchytSt.stl, Nosnik_3mm.stl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]
2021-07-09 Nahrani programu pro Arduino Nano.
2021-07-09 Tabulka k neliearnimu pomeru vykonu svetla vuci linearninu rizeni analogWrite(...)
    [Nastaveni_Svetla.ods]
2021-07-09 Test moto Z (CD ROM Stepper Motor)
2021-07-09 Arduino work 1
2021-07-10 Motory dokonceny. Netestovano.
2021-07-12 Pridani zamek na komunikaci. Pridan casovac pro aktualizaci. Opravene Arduino. Testovano...
2021-07-12 Ulozil jsem a zjistil jsme, ze v zamku je problem. V predchozich verzych to neni ulozene... I bez toho to funguje...
    [main.cpp]
2021-07-13 Aktualizace dokumentu
    [Nastaveni_Svetla.ods, Nastaveni_Svetla.xlsx]
2021-07-16 Uprava pohybu motoruZ
2021-07-19 Dokumentace osvetleni
    [Nastaveni_Svetla.xlsx]
2021-07-24 OpenScad pripraven na odevzdani
    [Tisk_3D_Objektu.scad]
2021-07-24 OpenScad pripraven na odevzdani 2
    [Tisk_3D_Objektu.scad]
2021-07-24 Finalni priprava souboru 1
    [Nastaveni_Svetla.xlsx]
2021-10-03 Pridani nových komponentu pro projekt
    [Tisk_3D_ObjektuV2.scad, Variable_Resistance_Connection_Block_LaLaRC.stl, gearmotor_pinion_12_gear_LaLaRC.stl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]
2021-10-06 Pridani předniho portu
    [Tisk_3D_ObjektuV2.scad, Tisk_3D_ObjektuV2a.stl, Tisk_3D_ObjektuV2aa.stl]
